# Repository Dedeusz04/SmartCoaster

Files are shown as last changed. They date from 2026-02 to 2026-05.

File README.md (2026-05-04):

# Smart Coaster - ESP8266 Beverage Temperature Monitor

An embedded system built on the **NodeMCU ESP8266** that detects cup presence, monitors beverage temperature in real time, and alerts the user when the drink has cooled to a configured target temperature.

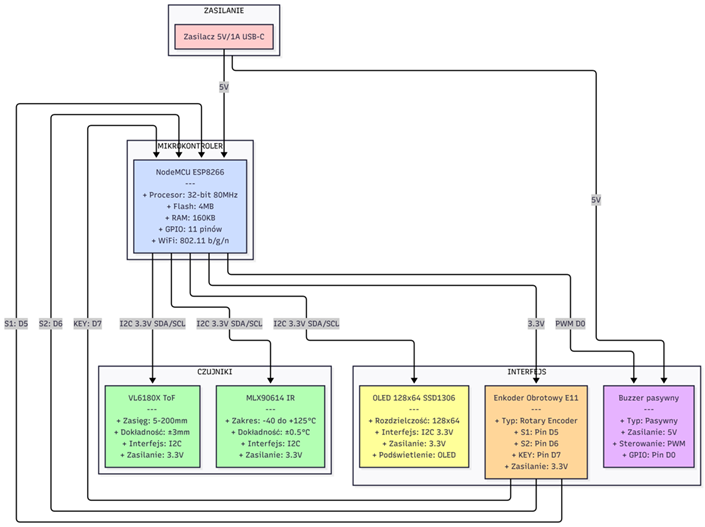
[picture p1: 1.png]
Block Diagram

gif

## Key Features

- Automatic cup detection (VL6180X ToF sensor)
- Non-contact temperature monitoring (MLX90614 IR sensor) with adaptive liquid temperature estimation
- Configurable brew timer and target drinking temperature
- 128×64 OLED display with rotary encoder menu
- Persistent user settings (EEPROM)
- Audible buzzer alerts
- **Mobile Push Notifications** via [ntfy.sh](https://ntfy.sh) (Max priority alarm)
- **Wi-Fi Connectivity** with network state reporting

For a detailed description, refer to the **project report** included in this repository [v1.Raport_Bartosz.Kępa.pdf](v1.Raport_Bartosz.Kępa.pdf).

## Pin Assignment

| Function | NodeMCU Pin | GPIO |
|---|---|---|
| I2C SDA | D2 | GPIO4 |
| I2C SCL | D1 | GPIO5 |
| Encoder S1 | D5 | GPIO14 |
| Encoder S2 | D6 | GPIO12 |
| Encoder Button | D7 | GPIO13 |
| Buzzer | D0 | GPIO16 |

## Build and Flash

Requires [PlatformIO](https://platformio.org/install/ide). All library dependencies are resolved automatically.

```bash
pio run              # compile
pio run -t upload    # flash to board
pio device monitor   # serial monitor (9600 baud)
```

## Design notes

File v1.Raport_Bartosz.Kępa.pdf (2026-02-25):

`

| Katedra Grafiki Wizji Komputerowej i Systemów Cyfrowych | RAu6
Rok akademicki: | Rodzaj studiów*: SSI/NSI/NSM | Przedmiot (Języki Asemblerowe/SMiW): | Grupa | Sekcja
2025/2026 | SSI | SMiW | 2 | 3
Imię: | Bartosz | Prowadzący: OA/JP/KT/GD/GB/KH/AO | JP
Nazwisko: | Kępa

## Raport końcowy SMIW

Temat projektu:
Podkładka pod kubek z funkcją timera i pomiarem temperatury napoju

Data oddania:
dd/mm/rrrr | 26/01/2026

## 1. Wprowadzenie i opis założeń

## 1.1. Cel projektu

Projekt zakłada opracowanie i wykonanie układu mikroprocesorowego pełniącego funkcję podkładki pod kubek. System reaguje na obecność naczynia, odmierza czas parzenia napoju oraz monitoruje temperaturę powierzchni naczynia/cieczy w czasie rzeczywistym.

## 1.2. Główne założenia projektowe

Detekcja obecności kubka
- Pomiar odległości w celu wykrycia obiektu na powierzchni podkładki
- Automatyczne przejście z trybu czuwania do trybu aktywnego po wykryciu kubka
- Zasięg detekcji obiektu: do 20 cm
- Dokładność pomiaru odległości: ±0,5 cm
Pomiar temperatury napoju
- Rejestracja temperatury w zakresie 0°C – 100°C
- Aktualna wartość wyświetlana na ekranie w czasie rzeczywistym
- Komunikat o osiągnięciu temperatury poniżej progu ustawionego przez użytkownika
- Dokładność pomiaru: ±1°C
Timer parzenia
- Odliczanie ustawionego czasu w zakresie 0–10 minut
- Wyświetlanie aktualnego stanu odliczania
- Sygnał dźwiękowy po upływie ustawionego czasu
- Dokładność timera: ±1 sekunda
Interfejs użytkownika
- Możliwość konfiguracji czasu i temperatury
- Czytelny wyświetlacz do prezentacji danych i komunikatów Parametry pracy
- Zakres temperatur otoczenia: 0°C – +40°C
- Zasilanie: 5V DC z zewnętrznego źródła (zasilacz USB-C)

## 2. Opis funkcji urządzenia

## 2.1. Zasada działania

Po wykryciu umieszczenia kubka w obszarze pomiarowym automatycznie uruchamia się odliczanie zaprogramowanego czasu parzenia. Po jego zakończeniu układ generuje sygnał dźwiękowy informujący użytkownika o gotowości napoju. W dalszej fazie urządzenie nadzoruje temperaturę, wyświetlając komunikaty, gdy ciecz osiągnie określony, bezpieczny poziom do spożycia.

## 2.2. Tryby pracy urządzenia

Stan | Opis
WAIT_CUP | Oczekiwanie na postawienie kubka, wyświetlanie komunikatu “Brak kubka”
MENU_TIME | Konfiguracja czasu parzenia (0-10 min) za pomocą enkodera
MENU_TEMP | Konfiguracja temperatury docelowej (0-100°C) za pomocą enkodera
BREWING | Odliczanie czasu parzenia z wyświetlaniem pozostałego czasu i temperatury
DONE | Monitorowanie temperatury do osiągnięcia progu
READY_TO_DRINK | Sygnalizacja gotowości napoju do spożycia

## 2.3. Maszyna stanów

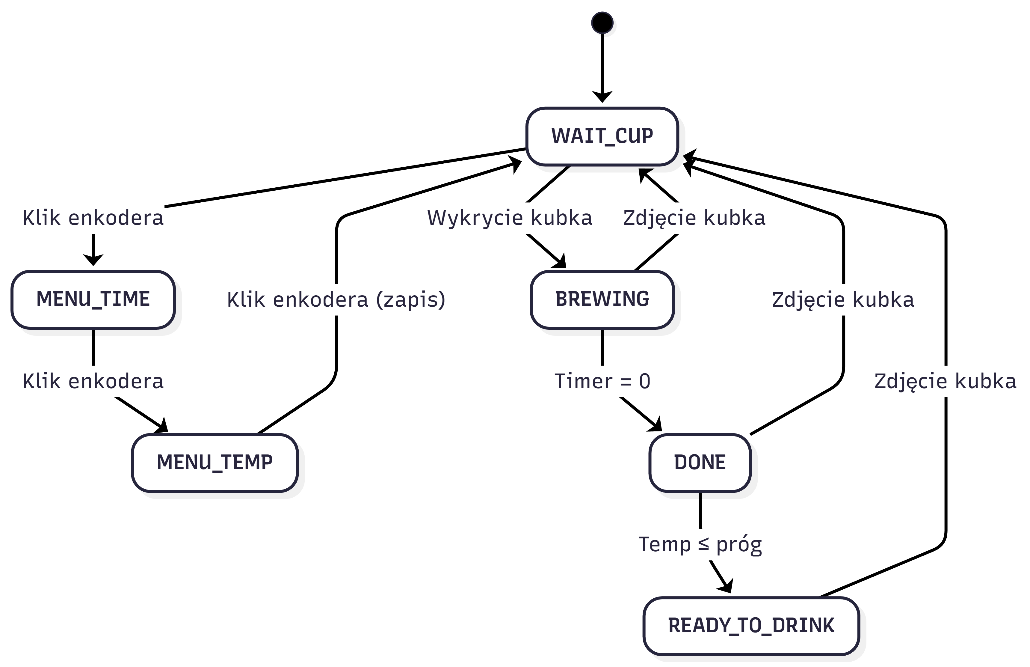
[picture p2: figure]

## 3. Analiza zadania i wybór komponentów

## 3.1. Analiza i wybór czujnika odległości

Wymagania: - Zasięg: do 20 cm
- Dokładność: ±0,5 cm
- Detekcja obecności kubka na podkładce
Porównanie dostępnych rozwiązań:
Parametr | VL6180X | HC-SR04 | GP2Y0A21YK0F | TFMini
Technologia | ToF laser | Ultradźwięki | Podczerwień (Sharp) | Lidar
Zakres pomiarowy | 5-200 mm | 20-4000 mm | 100-800 mm | 30-800 cm
Dokładność | ±3mm | ±3 mm | ±10 mm | ±600mm
Interfejs | I2C | GPIO (Trigger/Echo) | Analogowy | UART/I2C
Napięcie zasilania | 2.8-5V | 5V | 4.5-5.5V | 5V
Pobór prądu | ~20 mA | ~15 mA | ~30 mA | 70mA
Wymiary | 15×8×5 mm | 45×20×15 mm | 30×13×13 mm | 80x70x13m m
Cena orientacyjna | ~10-20 zł | ~5-8 zł | ~15-25 zł | ~50 zł
Zalety | Wysoka dokładność, kompaktowy, I2C | Tani, prosty w obsłudze | Dobra stabilność | Duży zasięg
Wady | Wymaga 3.3V | Duże wymiary, głośny | Niższa dokładność | Zbyt drogi

Wybór: VL6180X
Uzasadnienie: - Najwyższa dokładność pomiaru (±0,3 cm) spełniająca wymaganie ±0,5 cm
- Kompaktowe wymiary idealne do podkładki
- Interfejs I2C pozwala na łatwe połączenie z mikrokontrolerem
- Brak ruchomych części i cichy w działaniu
- Pomimo wyższej ceny, zapewnia profesjonalną jakość pomiaru

## 3.2. Analiza i wybór czujnika temperatury

Wymagania:
- Zakres: 0-100°C
- Dokładność: ±1°C
- Pomiar temperatury powierzchni kubka/napoju
Porównanie dostępnych rozwiązań:
Parametr | MLX90614ESF-BAA | DS18B20 | DHT22 | MAX6675 + termopara K
Typ pomiaru | Bezdotykowy (IR) | Dotykowy (OneWire) | Temperatura + wilgotność | Termopara
Zakres temperatury | -40 do +125°C | -55 do +125°C | -40 do +80°C | 0 do +1024°C
Dokładność | ±0,5°C (0-50°C) | ±0,5°C | ±0,5°C | ±2°C
Interfejs | I2C (SMBus) | 1-Wire | Własny protokół | SPI
Napięcie zasilania | 3.0-5V | 3.0-5.5V | 3.3-5.5V | 3.3-5V
Czas odpowiedzi | <1s | ~750ms (12-bit) | ~2s | ~0.5s
Cena orientacyjna | ~15-40 zł | ~8-12 zł | ~15-20 zł | ~25-35 zł
Zalety | Pomiar bezkontaktowy, szybki, precyzyjny | Tani, dokładny | Dodatkowa funkcja wilgotności | Wysokie temp.
Wady | Droższy | Wymaga kontaktu z cieczą | Wolny, mierzy powietrze | Wymaga kalibr.

Wybór: MLX90614ESF-BAA
Uzasadnienie: - Pomiar bezdotykowy idealny dla podkładki (czujnik pod kubkiem mierzy temperaturę dna)
- Wysoka dokładność ±0,5°C (lepiej niż wymagane ±1°C)
- Szybki czas odpowiedzi dla monitoringu w czasie rzeczywistym
- Interfejs I2C kompatybilny z VL6180X (można użyć tej samej magistrali)
- Profesjonalne rozwiązanie, bezpieczne (brak kontaktu z gorącym kubkiem)

## 3.3. Analiza i wybór wyświetlacza

Wymagania:
- Wyświetlanie temperatury, czasu, komunikatów
- Czytelność
- Możliwość podłączenia do mikrokontrolera
Porównanie dostępnych rozwiązań:
Parametr | LCD I2C 16×2 | OLED SSD1306 128×64 | LCD 16×2 (parallel) | TFT 1.8” ST7735
Rozdzielczość | 16 znaków × 2 linie | 128×64 pikseli | 16 znaków × 2 linie | 128×160 pikseli
Interfejs | I2C (2 piny) | I2C / SPI | Równoległy (6-8 pinów) | SPI (5 pinów)
Napięcie zasilania | 5V | 3.3-5V | 5V | 3.3-5V
Pobór prądu | ~20 mA | ~20 mA | ~20 mA | ~40mA
Kontrast/czytel ność | Bardzo dobry | Doskonały, wysoki kontrast | Bardzo dobry | Dobry
Wymiary | 80×36×18 mm | 27×27×4 mm | 80×36×12 mm | 35×50×5 mm
Cena orientacyjna | ~12-18 zł | ~6-25 zł | ~10-15 zł | ~20-30 zł
Zalety | Prosty I2C, duże znaki | Kompaktowy, graficzny, elegancki | Najtańszy | Kolorowy
Wady | Większe wymiary | Wymaga biblioteki graficznej | Zajmuje dużo GPIO | Wymaga więcej RAM

Wybór: OLED SSD1306 (zmiana względem analizy)
Uzasadnienie: - Kompaktowe wymiary (27×27×4 mm)
- Wysoki kontrast i czytelność
- Możliwość wyświetlania grafiki i większych czcionek
- Energooszczędny, komunikacja i2c, działanie na 3,3V

## 3.4. Analiza i wybór przycisków sterujących

Wymagania:
- Konfiguracja czasu i temperatury
- Minimum 3 przyciski (menu, góra, dół)
Porównanie dostępnych rozwiązań:
Parametr | Tact Switch 6×6mm | Przyciski membranowe | Przyciski kapturowe | EC11 Rotary Encoder
Typ | Mikroswitch taktylny | Membrana z kontaktem | Przycisk z osłoną | Encoder z przyciskiem
Trwałość | 100 000 cykli | 1 000 000 cykli | 50 000 cykli | 30 000 obrotów
Siła nacisku | ~160 gF | ~200-300 gF | ~250 gF | Obrót: ~100 gF
Wymiary | 6×6×5 mm | 12×12 mm | 12×12 mm | 12.5×12.5 mm
Cena (3 szt.) | ~1-2 zł | ~8-15 zł | ~3-6 zł | ~3-5 zł (1 szt.)
Zalety | Tanie, kompaktowe | Profesjonalny wygląd | Estetyczne | Intuicyjna obsługa, 3 funkcje w 1
Wady | Wymaga nakładek | Droższe | Większe wymiary | Droższy, większy

Wybór: EC11 Rotary Encoder z przyciskiem
Uzasadnienie: - Intuicyjna obsługa
– obracanie jest bardziej naturalne niż wielokrotne klikanie
- Szybka nawigacja zmiana wartości (czas 0-10 min, temperatura 0-100°C) jest znacznie szybsza
- 3 funkcje w 1 elemencie: obrót lewo/prawo + wciśnięcie
- Oszczędność miejsca – zamiast 3 przycisków tylko 1 komponent
- Taktylny feedback – kliknięcia przy obrocie (20 impulsów/obrót)

## 3.5. Analiza i wybór buzzera

Wymagania:
- Sygnalizacja dźwiękowa po zakończeniu timera
- Wyraźny dźwięk
Porównanie dostępnych rozwiązań:
Parametr | Buzzer pasywny | Buzzer aktywny | Głośniczek piezo
Typ | Wymaga sygnału PWM | Wbudowany generator | Piezoelektryczny
Napięcie | 3-12V | 3-12V | 3-24V
Głośność | 80-90 dB (regulowana) | 85 dB (stała) | 70-100 dB
Możliwości | Różne melodie/tony | Jeden stały ton | Różne częstotliwości
Sterowanie | PWM (1 pin) | ON/OFF (1 pin) | PWM (1 pin)
Cena orientacyjna | ~1-4 zł | ~2-3 zł | ~3-6 zł
Zalety | Możliwość melodii | Najprostszy w obsłudze | Najgłośniejszy
Wady | Wymaga programowania PWM | Brak zmiany tonu | Droższy

Wybór: Buzzer pasywny
Uzasadnienie: - Możliwość zaprogramowania różnych melodii/tonów dla różnych zdarzeń -Regulacja głośności przez zmianę wypełnienia PWM - Większa elastyczność funkcjonalna -ESP8266 bez problemu generuje sygnał PWM

## 3.6. Analiza i wybór mikrokontrolera

Podsumowanie wymagań interfejsów:
- I2C: 3 urządzenia (OLED, VL6180X, MLX90614)
– 2 piny (SDA, SCL) - GPIO cyfrowe: EC11 Rotary Encoder – 3 piny - PWM: 1 buzzer
– 1 pin - Łącznie: minimum 4 pinów GPIO + I2C
Porównanie dostępnych rozwiązań:
Parametr | NodeMCU ESP8266 | Arduino Nano | STM32F103 | Arduino Uno
Procesor | Tensilica L106 32-bit | ATmega328P 8-bit | ARM Cortex-M3 | ATmega328P
Częstotliwo ść | 80/160 MHz | 16 MHz | 72 MHz | 16 MHz
Flash | 4 MB | 32 KB | 64/128 KB | 32 KB
RAM | 160 KB | 2 KB | 20 KB | 2 KB
GPIO | 11 pinów | 14 pinów | 37 pinów | 14 pinów
Interfejsy | I2C, SPI, UART, PWM | I2C, SPI, UART, PWM | 2×I2C, 2×SPI, PWM | I2C, SPI, UART
Napięcie logiki | 3.3V | 5V | 3.3V | 5V
Wbudowane WiFi | Tak | Nie | Nie | Nie
Pobór prądu | ~80 mA | ~20 mA | ~40 mA | ~53 mA
Cena orientacyjna | ~15-25 zł | ~20-30 zł | ~10-15 zł | ~25-35 zł

Wybór: NodeMCU ESP8266
Uzasadnienie:
- Wystarczająca liczba GPIO: 11 pinów (potrzeba 4 + I2C)
- Wbudowany moduł WiFi: możliwość przyszłej rozbudowy (zdalna kontrola, notyfikacje)
- Szybki procesor: 80 MHz zapewnia płynne działanie timera i odświeżania wyświetlacza
- Duża pamięć: 4 MB Flash, 160 KB RAM- komfortowe programowanie
- I2C hardware: wbudowana obsługa magistrali I2C

-PWM: możliwość generowania sygnału dla buzzera
- Społeczność: ogromne wsparcie, biblioteki, przykłady

## 3.7. Analiza zasilania

Wymagania prądowe (maksymalne):

Urządzenie | Napięcie | Prąd
NodeMCU ESP8266 3.3V (z 5V) 200 mA
OLED SSD 1306 | 3.3V | 20 mA
VL53L0X | 3.3V | 20 mA
MLX90614 | 3.3V | 5 mA
Przyciski | - | <1 mA
Buzzer pasywny | 5V | 30 mA
SUMA | 5V | ~275 mA

Porównanie źródeł zasilania:

Źródło | Napięcie wyjściowe | Prąd max | Zastosowanie | Cena
Zasilacz sieciowy 5V/1A | 5V DC | 1000 mA | Stacjonarne urządzenia | ~10-15 zł
Powerbank USB 5V | 5V DC | 1000-2000 mA | Mobilne | ~30-50 zł
Baterie 4×AA z przetwórnicą | 5V DC (z 6V) | 500 mA | Przenośne | ~20 zł (baterie + przetwornica)

Wybór: Zasilacz sieciowy 5V/1A (wtyk USB-C)

Uzasadnienie:

- Pobór prądu ~275 mA << 1000 mA (duży zapas bezpieczeństwa)
- Urządzenie stacjonarne (podkładka pod kubek) – nie wymaga mobilności
- Najbardziej ekonomiczne i stabilne rozwiązanie
- NodeMCU posiada port USB-C do zasilania
- Brak konieczności wymiany baterii

## 3.8 Analiza różnych sposobów rozwiązania zadania

Koncepcja A: Układ z czujnikami bezkontaktowymi (WYBRANA) Opis: Czujnik laserowy ToF (VL6180X) + czujnik IR (MLX90614) + ESP8266 Zalety:
- Brak kontaktu fizycznego z kubkiem (higieniczne)
- Wysoka dokładność obu pomiarów
- Możliwość rozbudowy o WiFi/IoT
- Kompaktowa konstrukcja
Wady:
- Wyższy koszt (~140 zł)
- Czujnik IR wymaga kalibracji dla różnych materiałów

Koncepcja B: Układ z czujnikami dotykowymi
Opis: Czujnik ultradźwiękowy (HC-SR04) + sonda dotykowa (DS18B20) Zalety:
- Niższy koszt (~80 zł, oszczędność 60 zł)
- Bardzo dokładny pomiar temperatury przy kontakcie
- Prostsza kalibracja
Wady:
- Wymaga precyzyjnego ustawienia kubka
- Sonda może się brudzić
- Większe wymiary czujnika ultradźwiękowego
- Mniej profesjonalny wygląd

Koncepcja C: Układ z wagą elektroniczną
Opis: Czujnik wagi (HX711 + load cell) + termopara K Zalety:
- Niezawodna detekcja kubka (pomiar masy)
- Możliwość dodatkowych funkcji (pomiar ilości płynu)
- Termopara działa do 1000°C
Wady:
- Skomplikowana konstrukcja mechaniczna
- Najwyższy koszt (~180 zł)
- Większe wymiary
- Trudniejsza kalibracja

Wybór: Koncepcja A - optymalne połączenie dokładności, higieny i możliwości rozbudowy przy akceptowalnym koszcie.

## 4. Zmiany wprowadzone po analizie

## 4.1. Zmiana wyświetlacza

Aspekt | Analiza (LCD I2C 16×2) | Realizacja (OLED SSD1306)
Rozdzielczość | 16×2 znaki | 128×64 pikseli
Kontrast | Podświetlenie LED | Samoemisyjny, wysoki kontrast
Wymiary | 80×36×18 mm | 27×27×4 mm
Biblioteka | LiquidCrystal_I2C | ss_oled

Uzasadnienie: OLED oferuje większą elastyczność w wyświetlaniu informacji, mniejsze wymiary i lepszy wygląd urządzenia.

## 4.2. Sterowanie buzzerem

Aspekt | Analiza | Realizacja
Zasilanie | 3.3V bezpośrednio | 5V przez tranzystor
Sterowanie | GPIO bezpośrednio | PWM → 2N2222 → Buzzer
Zabezpieczenie | Brak | Dioda DO-213AA(SOD-80)

Uzasadnienie: Buzzer 5V zapewnia głośniejszy dźwięk. Tranzystor 2N2222 odciąża GPIO ESP8266, a dioda zabezpieczająca chroni tranzystor przed przepięciami indukcyjnymi.

## 4.3. Konstrukcja dwupłytkowa

Płytka | Komponenty
Główna (Main PCB) | ESP8266, OLED, Rotary Encoder, Buzzer, złącze J1
Czujników (Sensor PCB) | VL6180X, MLX90614, złącze J1

Połączenie: Kable DuPont przez złącze 2×5 pin (5-534237-8)
Uzasadnienie: Rozdzielenie pozwala na umieszczenie czujników w optymalnej pozycji względem kubka, niezależnie od elektroniki głównej.

## 5. Specyfikacja wewnętrzna urządzenia

## 5.1. Schemat blokowy

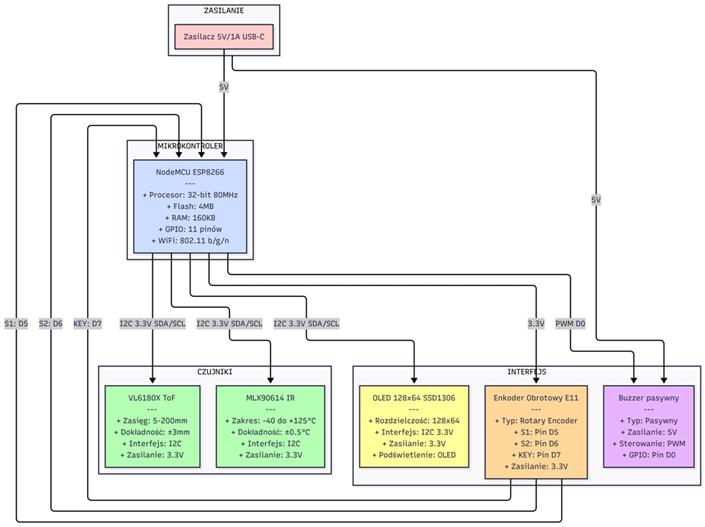
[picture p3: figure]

Schemat blokowy systemu
Opis połączeń:
- Zasilanie: 5V/1A USB-C → NodeMCU ESP8266 (wbudowany regulator 3.3V)
- Magistrala I2C: SDA (D2), SCL (D1) → OLED, MLX90614, VL6180X
- Enkoder: S1 (D5), S2 (D6), KEY (D7)
- Buzzer: PWM (D0) → Tranzystor → Buzzer 5V

## 5.2. Schemat ideowy

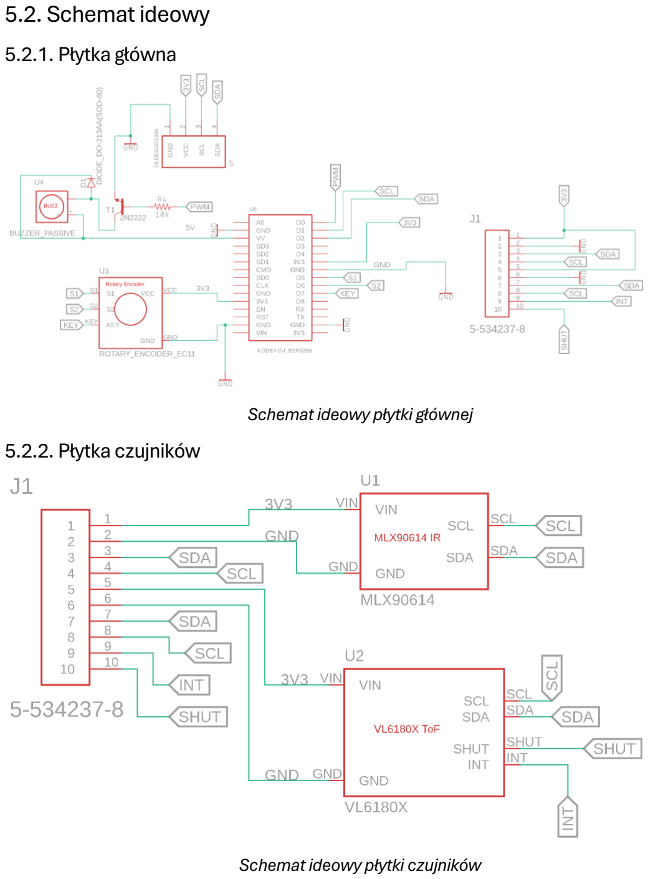
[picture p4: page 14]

5.2.1. Płytka główna

Schemat ideowy płytki głównej
5.2.2. Płytka czujników

Schemat ideowy płytki czujników

## 5.3. Opis bloków funkcjonalnych

5.3.1. Blok zasilania

Układ zasilany jest z zewnętrznego zasilacza 5V/1A przez port USB-C modułu NodeMCU. Wbudowany regulator napięcia AMS1117-3.3 dostarcza napięcie 3.3V dla:
- Czujnika VL6180X
-Czujnika MLX90614
- Wyświetlacza OLED
- Enkodera obrotowego
Buzzer zasilany jest bezpośrednio z 5V.
5.3.2. Blok pomiaru odległości (VL6180X)

Czujnik ToF mierzy odległość do obiektu (kubka) w zakresie 5-200 mm. Komunikacja I2C na adresie 0x29. Pomiar wykonywany co 400 ms w celu oszczędzania energii i ochrony termicznej.

Funkcja measureDistance():

1. float measureDistance() {
2. uint8_t range = vl.readRange();
3. return (vl.readRangeStatus() == VL6180X_ERROR_NONE) ? range : -1;
4. }
5.3.3. Blok pomiaru temperatury (MLX90614)

Czujnik IR mierzy temperaturę obiektu bezdotykowo. Komunikacja I2C na adresie 0x5A. Pomiar temperatury z funkcją estymacji temperatury cieczy.
Algorytm estymacji temperatury kompensuje różnicę między temperaturą dna kubka a rzeczywistą temperaturą cieczy:
1. float estimateLiquidTemp(float rawBottomTemp, float ambientTemp) {
2. float diff = rawBottomTemp - ambientTemp;
3. float adaptiveCoeff = baseFactor * coefficientTable[diff];
4. return rawBottomTemp + (diff * adaptiveCoeff);
5. }
5.3.4. Blok interfejsu użytkownika

Wyświetlacz OLED SSD1306:
- Adres I2C: 0x3C
- Biblioteka: ss_oled

- Tryby wyświetlania: FONT_NORMAL, FONT_STRETCHED Enkoder EC11: - Obsługa przerwań na pinach S1 i S2 (CHANGE)
- Dekodowanie quadrature dla dokładnej detekcji kierunku
- Przycisk z debounce 250 ms
5.3.5. Blok sygnalizacji dźwiękowej

Buzzer pasywny sterowany PWM przez tranzystor 2N2222:
- Rezystor bazowy: 10kΩ
- Dioda zabezpieczająca: DO-213AA
- Funkcja beep(frequency, duration) generuje sygnał PWM

## 5.4. Schemat montażowy i projekt PCB

5.4.1. Płytka główna - warstwa TOP (czerwona)

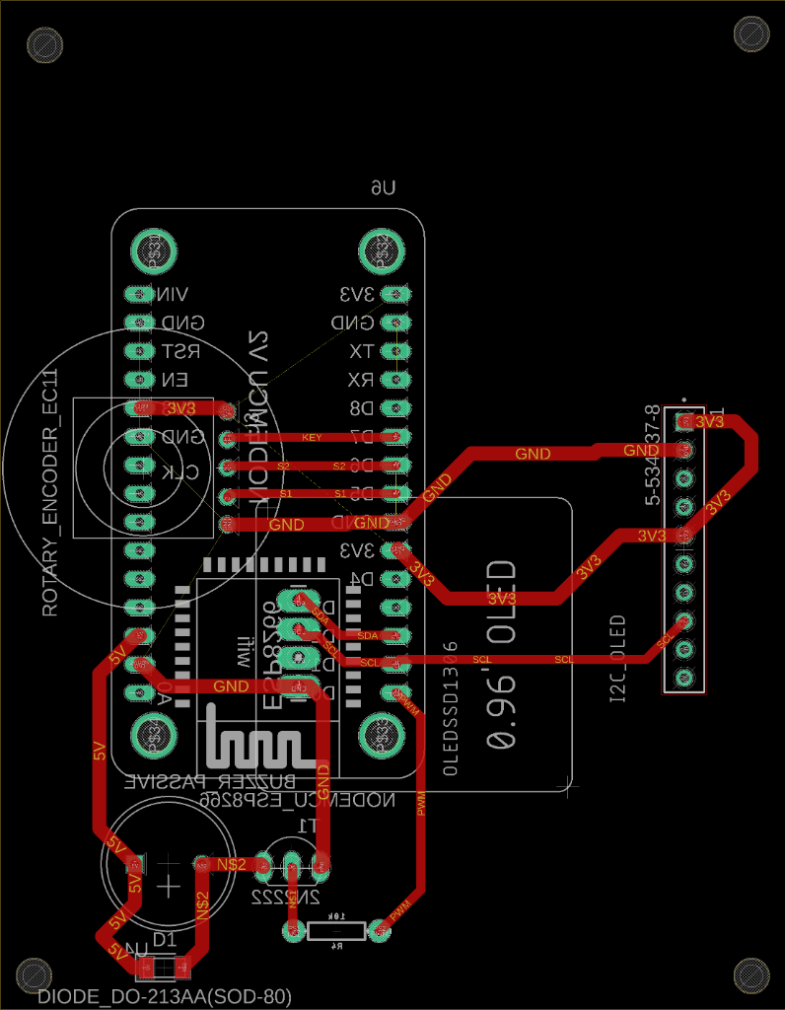
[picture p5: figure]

PCB płytki głównej - warstwa TOP

5.4.2. Płytka główna - warstwa BOTTOM (niebieska)

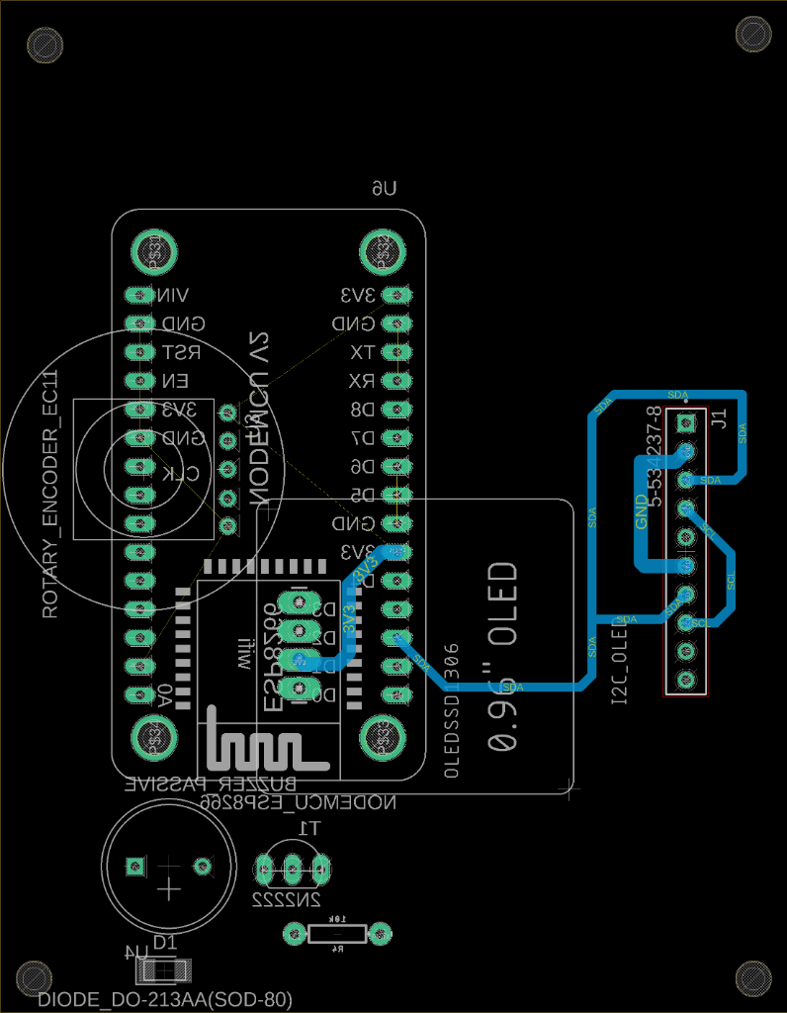
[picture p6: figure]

PCB płytki głównej - warstwa BOTTOM

5.4.3. Płytka czujników - warstwa TOP (czerwona)

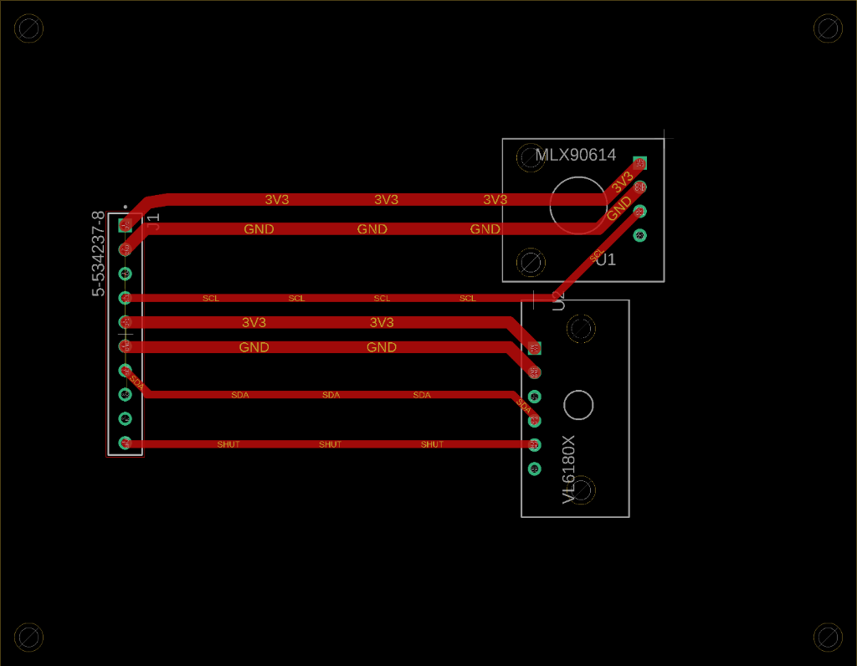
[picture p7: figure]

PCB płytki czujników - warstwa TOP

5.4.4. Płytka czujników - warstwa BOTTOM (niebieska)

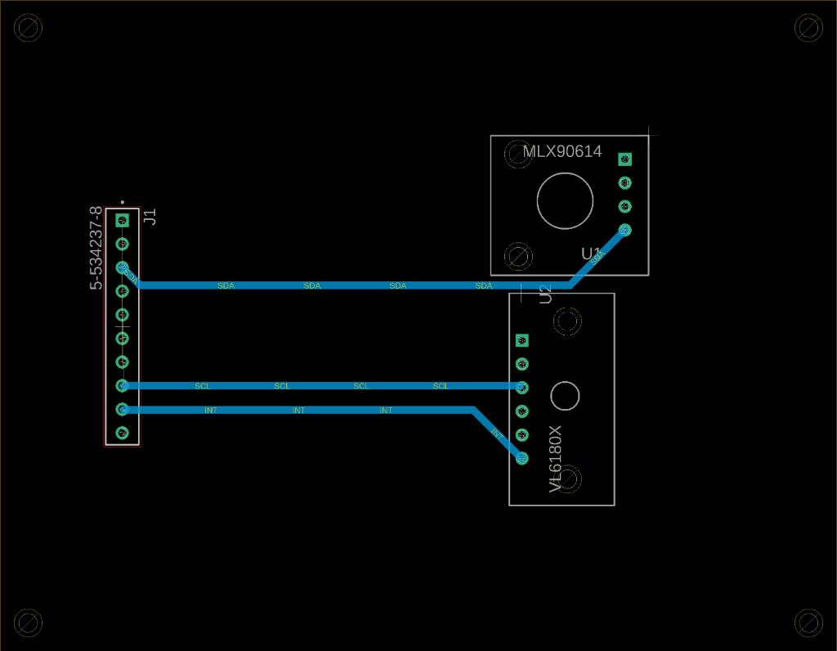
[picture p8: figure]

PCB płytki czujników - warstwa BOTTOM

## 5.5. Lista elementów

Płytka główna
Oznaczenie | Element | Wartość/Typ | Ilość | Cena
U6 | Mikrokontroler | NodeMCU ESP8266 | 1 | 15 zł
U7 | Wyświetlacz | OLED SSD1306 128×64 0.96” | 1 | 6 zł
U3 | Enkoder | EC11 z przyciskiem | 1 | 3.50 zł
U4 | Buzzer | Pasywny 5V | 1 | 1 zł
T1 | Tranzystor | 2N2222 | 1 | 0.5 zł
D1 | Dioda | DO-213AA(SOD-80) | 1 | 0.5 zł
R4 | Rezystor | 10kΩ | 1 | 0.1 zł
J1 | Złącze | 5-534237-8 (5 pin) | 2 | 1 zł
- | Złącza do modułów | 5-534237-8 (4,5,15,2 pin) | 5 | 1.5 zł
- | PCB | Płytka uniwersalna | 2 | 4 zł

Płytka czujników
Oznaczenie | Element | Wartość/Typ | Ilość | Cena
U1 | Czujnik temperatury | MLX90614ESF-BAA | 1 | 15 zł
U2 | Czujnik odległości | VL6180X ToF | 1 | 10 zł
J1 | Złącze | 5-534237-8 (5 pin) | 2 | 1 zł
- | Złącza do modułów | 5-534237-8 (4pin) | 2 | 1 zł
Inne
Element | Opis | Ilość | Cena
Kable DuPont | Male-male | 8 | 1 zł
Zasilacz | 5V/1A USB-C | 1 | 10 zł
Przewody | Różne do montażu | - | ~1 zł
Obudowa | Pudełko plastikowe | 1 | 7 zł

Suma: ~79.1 zł

## 5.6. Opis montażu

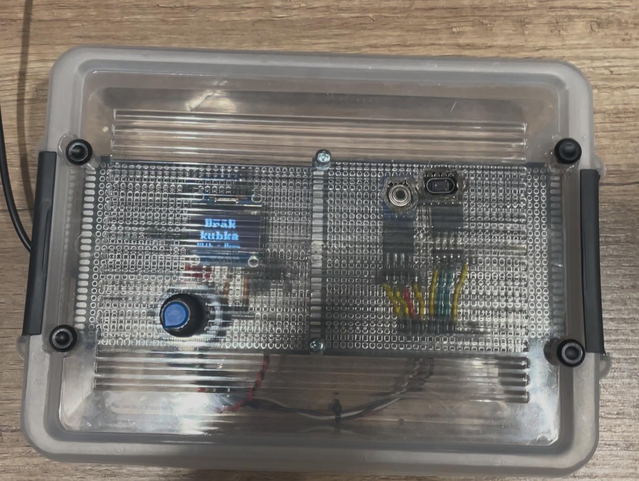
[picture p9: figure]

Widok urządzenia w obudowie

Urządzenie zostało umieszczone w obudowie z tworzywa sztucznego z przezroczystą pokrywą. Układ elektroniczny, zmontowany na płytce uniwersalnej, został trwale przymocowany do wewnętrznej strony pokrywy za pomocą śrub montażowych.
W pokrywie wykonano otwory dla kluczowych elementów interfejsu i sensorów.
Takie rozwiązanie konstrukcyjne zapewnia ochronę mechaniczną układu przy jednoczesnym zachowaniu funkcjonalności sensorów i czytelności wyświetlacza OLED Urządzenie składa się z dwóch płytek PCB połączonych kablem DuPont male-male przez złącza 2×5pin (5-534237-8). Wszystkie moduły posiadają goldpiny male, a do płytki podłączane są przez connectory (goldpiny) female, co umożliwia łatwą wymianę komponentów.
Płytka główna - podłączenie modułów:
Moduł | Złacza na PCB | Piny
NodeMCU ESP8266 | Connector 2×15 fem. | Wszystkie piny modułu
OLED SSD1306 | Connector 1×4 fem. | GND, VCC, SCL, SDA
Enkoder EC11 | Connector 1×5 fem. | S1, S2, KEY, VCC, GND
Buzzer pasywny | Connector 1×2 fem. | +, - (przez tranzystor)
Złącze J1 | Connector 2×5 fem. | Do płytki czujników
Płytka czujników - podłączenie modułów:
Moduł | Złącza na PCB | Piny
MLX90614 | Connector 1×4 fem. | VIN, GND, SCL, SDA
VL6180X | Connector 1×4 fem. | VIN, GND, SCL, SDA, (SHUT, INT)-nieużywane
Złącze J1 | Connector 2×5 fem. | Do płytki głównej

Połączenie płytek kablem DuPont (9-10 pusty):
Pin | Płytka główna | Płytka czujników
1 | 3V3 | VIN (MLX90614)
2 | GND | GND (MLX90614)
3 | SDA (D2) | SDA (MLX90614)
4 | SCL (D1) | SCL (MLX90614)
5 | 3V3 | VIN (VL6180X)
6 | GND | GND (VL6180X)
7 | SDA (D2) | SDA (VL6180X)
8 | SCL (D1) | SCL (VL6180X)

## 5.7. Programowanie układu

5.7.1. Środowisko programistyczne
- IDE: PlatformIO (w Visual Studio Code)
- Framework: Arduino
- Platforma: espressif8266
- Board: nodemcuv2
5.7.2. Konfiguracja projektu (platformio.ini)
1. [env:nodemcuv2]
2. platform = espressif8266
3. board = nodemcuv2
4. framework = arduino
5. monitor_speed = 115200
6.
7. lib_deps =
8. Wire
9. SPI
10. Adafruit BusIO
11. Adafruit Unified Sensor
12. https://github.com/adafruit/Adafruit-MLX90614-Library.git
13. https://github.com/adafruit/Adafruit_VL6180X.git
14. https://github.com/bitbank2/ss_oled.git
15.
16. build_flags =
17. -D PIO_FRAMEWORK_ARDUINO_ESPRESSIF_SDK22x_191122 18.
19. board_build.ldscript = eagle.flash.4m1m.ld
5.7.3. Procedura programowania
1. Podłączyć NodeMCU do komputera przez USB
2. Wybrać odpowiedni port COM w PlatformIO
3. Skompilować projekt: pio run
4. Wgrać firmware: pio run --target upload
5. Otworzyć monitor szeregowy: pio device monitor

## 5.8. Uruchamianie i testowanie

5.8.1. Procedura uruchomienia
1. Podłączyć zasilacz 5V/1A
2. Obserwować sekwencję startową na wyświetlaczu:
- “Coaster” - logo startu
- “Sensors: MLX: OK, VL: OK” - status czujników
3. Po ~2 sekundach wyświetla się “Brak kubka”
5.8.2. Testy funkcjonalne
Test | Procedura | Oczekiwany rezultat
Detekcja kubka | Umieścić kubek nad czujnikiem | Wyświetla “Kubek wykryty”, rozpoczyna parzenie
Timer | Ustawić czas, postawić kubek | Odliczanie widoczne na ekranie
Pomiar temperatury | Postawić gorący kubek | Wyświetla temperaturę estymowaną
Enkoder | Obracać pokrętło w menu | Zmiana wartości czasu/temperatury
Buzzer | Zakończyć timer | Dźwięk sygnalizacyjny
Zapis EEPROM | Zmienić ustawienia, wyłączyć/włączyć | Ustawienia zachowane
5.8.3. Weryfikacja czujników

Monitor szeregowy wyświetla co 5 sekund:
Raw: XX.XC, Est: XX.XC, Peak: XX.XC

## 5.9. Algorytm oprogramowania

5.9.1. Schemat blokowy programu

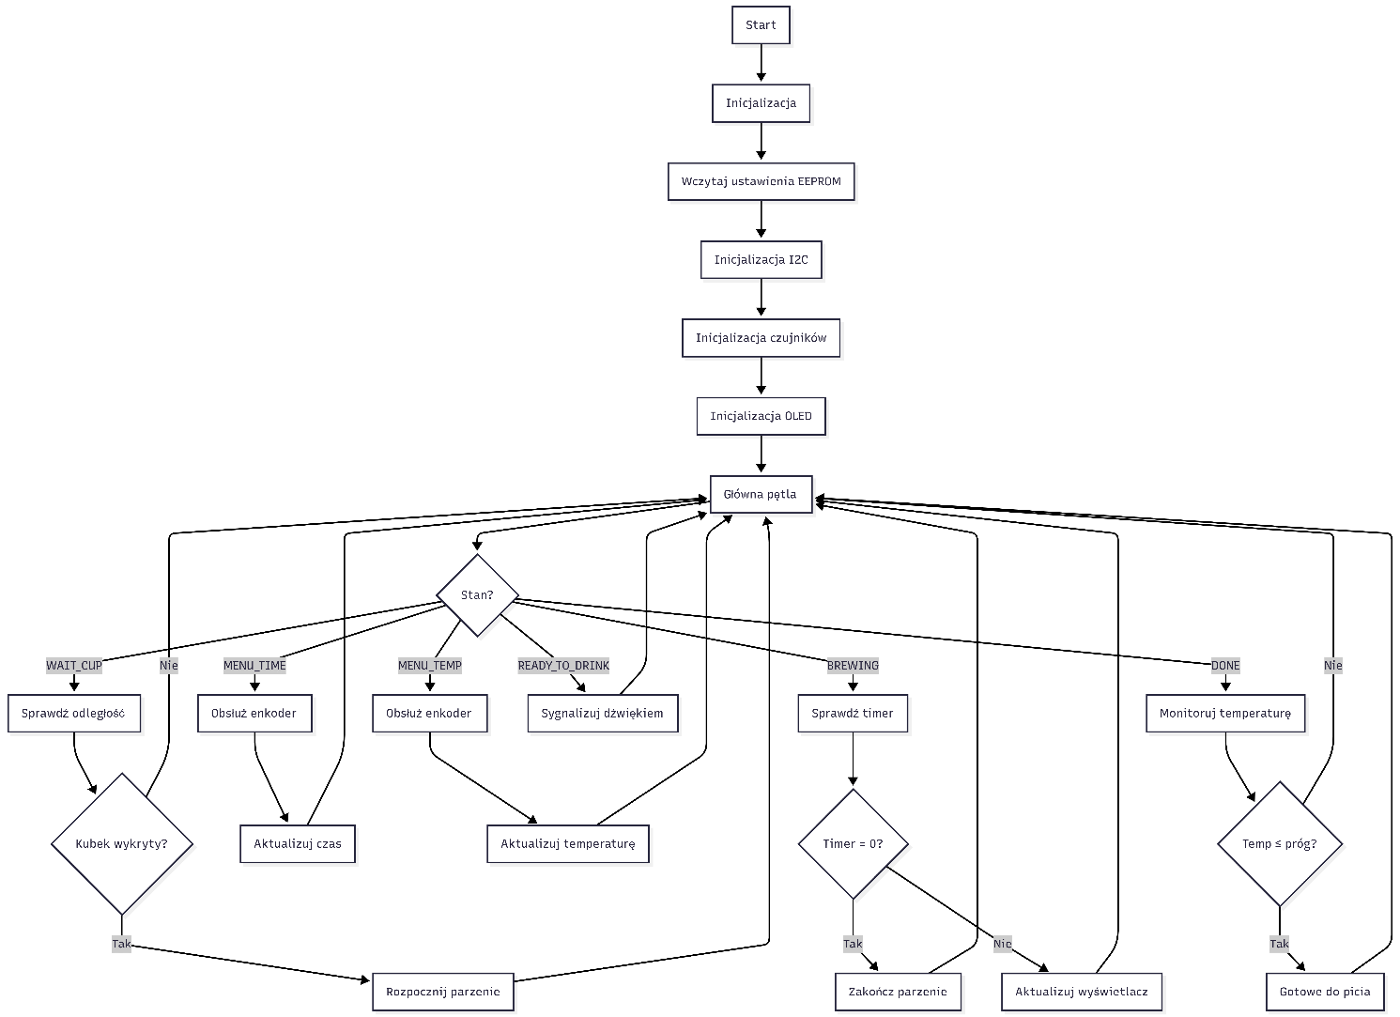
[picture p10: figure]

## 5.10. Opis zmiennych

Zmienne globalne - ustawienia
Zmienna | Typ | Zakres | Opis
timeSet | unsigned long | 0-600 | Ustawiony czas parzenia [s]
tempThreshold | float | 0-100 | Temperatura docelowa [°C]
brewDuration | unsigned long | 0-600 | Aktualny czas parzenia [s]
brewStartTime | unsigned long | - | Znacznik czasu rozpoczęcia parzenia [ms]

Zmienne globalne - stan
Zmienna | Typ | Opis
state | enum State | Aktualny stan maszyny stanów
cupDetected | bool | Flaga wykrycia kubka
currentTemp | float | Aktualna estymowana temperatura cieczy [°C]
rawBottomTemp | float | Surowa temperatura dna kubka [°C]
peakTemp | float | Szczytowa temperatura zarejestrowana [°C]
fixedAmbient | float | Snapshot temperatury otoczenia przy postawieniu kubka [°C]

Zmienne globalne - enkoder
Zmienna | Typ | Opis
encoderPosition | volatile int | Pozycja enkodera (aktualizowana przez przerwania)
lastEncoded | volatile int | Poprzedni stan pinów enkodera
lastButtonTime | unsigned long | Znacznik czasu ostatniego naciśnięcia przycisku

Zmienne globalne - wyświetlacz
Zmienna | Typ | Opis
needDisplayUpdate | bool | Flaga konieczności odświeżenia wyświetlacza
lastDrawnState | State | Ostatni narysowany stan (optymalizacja rysowania)
lastDisplayDrawTime | unsigned long | Znacznik czasu ostatniego odświeżenia

Stałe konfiguracyjne
Stała | Wartość | Opis
MAX_DISTANCE | 200 | Maksymalna odległość

Stała | Wartość | Opis
| | detekcji kubka [mm]
MIN_TIME / MAX_TIME | 0 / 600 | Zakres czasu parzenia [s]
MIN_TEMP / MAX_TEMP | 0 / 100 | Zakres temperatury docelowej [°C]
DEFAULT_TIME | 180 | Domyślny czas parzenia (3 min)
DEFAULT_TEMP | 55 | Domyślna temperatura docelowa [°C]
SAFETY_TEMP_THRESHOLD | 45.0 | Próg ochrony termicznej czujnika [°C]

## 5.11. Opis procedur

5.11.1. Procedura setup()

Cel: Inicjalizacja systemu
Działanie: 1. Inicjalizacja UART (115200 baud) dla debugowania
2. Wczytanie ustawień z EEPROM
3. Konfiguracja pinów GPIO (enkoder, buzzer)
4. Podłączenie przerwań do pinów enkodera
5. Inicjalizacja magistrali I2C (100 kHz)
6. Inicjalizacja wyświetlacza OLED
7. Inicjalizacja czujników MLX90614 i VL6180X
8. Wyświetlenie statusu inicjalizacji
9. Snapshot temperatury otoczenia
5.11.2. Procedura loop()

Cel: Główna pętla programu
Działanie: 1. Obsługa enkodera (odczyt pozycji, przycisk)
2. Sprawdzanie odległości (detekcja kubka) co 400 ms

3. Obsługa alarmu gotowości (beep co 2 s)
4. Odczyt temperatury co 1 s (gdy kubek wykryty)
5. Logika wykrywania gotowości do picia
6. Reset stanu przy zdjęciu kubka
7. Obsługa timera parzenia
8. Aktualizacja wyświetlacza
5.11.3. Procedura handleEncoderInterrupt() (ISR)

Cel: Obsługa przerwania enkodera z dekodowaniem quadrature Typ: IRAM_ATTR (funkcja przerwania)
Działanie:
1. void IRAM_ATTR handleEncoderInterrupt() {
2. int MSB = digitalRead(ENC_S1);
3. int LSB = digitalRead(ENC_S2);
4. int encoded = (MSB << 1) | LSB;
5. int sum = (lastEncoded << 2) | encoded;
6.
7. // Tablica stanów
8. if(sum == 0b1101 || sum == 0b0100 || sum == 0b0010 || sum == 0b1011) {
9. encoderPosition++;
10. }
11. if(sum == 0b1110 || sum == 0b0111 || sum == 0b0001 || sum == 0b1000) {
12. encoderPosition--;
13. }
14. lastEncoded = encoded;
15. }
Opis: Funkcja dekoduje sygnały A i B enkodera metodą quadrature, co pozwala na dokładne wykrycie kierunku obrotu. Przerwanie wywoływane jest przy każdej zmianie stanu (CHANGE) na obu pinach.
5.11.4. Procedura estimateLiquidTemp()

Cel: Estymacja temperatury cieczy na podstawie temperatury dna kubka
Parametry: - rawBottomTemp - temperatura dna kubka [°C] - ambientTemp - temperatura otoczenia [°C]
Zwraca: Estymowana temperatura cieczy [°C]

Algorytm: 1. Oblicz różnicę: diff = rawBottomTemp - ambientTemp
2. Wybierz współczynnik adaptacyjny na podstawie zakresu różnicy
3. Oblicz estymację: liquidTemp = rawBottomTemp + (diff * adaptiveCoeff)
5.11.5. Procedura encoderClick()

Cel: Obsługa kliknięcia przycisku enkodera
Maszyna stanów: - WAIT_CUP → MENU_TIME
- MENU_TIME → MENU_TEMP
- MENU_TEMP → WAIT_CUP (z zapisem ustawień) Działanie:
1. void encoderClick() {
2. State oldState = state;
3. if (state == WAIT_CUP) state = MENU_TIME;
4. else if (state == MENU_TIME) state = MENU_TEMP;
5. else if (state == MENU_TEMP) {
6. state = WAIT_CUP;
7. saveSettings();
8. beep(2500, 20);
9. }
10. if (oldState != state) {
11. beep(2000, 20);
12. needDisplayUpdate = true;
13. }
14. }
5.11.6. Procedura drawScreenContent()

Cel: Rysowanie zawartości ekranu w zależności od stanu Tryby wyświetlania:

Stan | Zawartość ekranu
WAIT_CUP (brak kubka) | “Brak kubka” + “Klik = Menu”
WAIT_CUP (kubek) | “Kubek wykryty”
MENU_TIME | “Czas parzenia: MM:SS”
MENU_TEMP | “Ustaw Temp: XX C”
BREWING | “Parzenie” + “MM:SS” + “Liq: XX C”
DONE | “Stygnie/Grzanie” + “Cel: XX C” + “Akt: XX C”
READY_TO_DRINK | “GOTOWE!” + “XX C”

5.11.7. Procedury pomocnicze
Procedura | Opis
loadSettings() | Wczytuje czas i temperaturę z EEPROM
saveSettings() | Zapisuje czas i temperaturę do EEPROM
measureDistance() | Odczytuje odległość z VL6180X
startBrewing() | Inicjalizuje stan BREWING
finishBrewing() | Kończy parzenie, przechodzi do DONE
remaining() | Oblicza pozostały czas parzenia
beep(freq, dur) | Generuje dźwięk buzzera
formatTime(sec, buf) | Formatuje sekundy do MM:SS
triggerReady() | Przechodzi do stanu READY_TO_DRINK

## 6. Specyfikacja zewnętrzna urządzenia

## 6.1. Elementy sterujące

Enkoder obrotowy EC11
Akcja | Funkcja
Obrót w prawo | Zwiększenie wartości (czas +10s, temp +1°C)
Obrót w lewo | Zmniejszenie wartości (czas -10s, temp -1°C)
Kliknięcie | Przełączanie menu / zatwierdzenie
Sekwencja menu
WAIT_CUP → [KLIK] → MENU_TIME → [KLIK] → MENU_TEMP → [KLIK] → WAIT_CUP (zapis)

## 6.2. Elementy wykonawcze

Wyświetlacz OLED 0.96” 128×64
- Wyświetla aktualny stan urządzenia
- Pokazuje temperaturę i czas
- Komunikaty w języku polskim
Buzzer
- Krótki beep (20 ms): potwierdzenie akcji

- Dwa beeepy (100 ms): koniec parzenia
- Ciągły beep co 2s: gotowe do picia

## 6.3. Reakcja na zdarzenia zewnętrzne

Zdarzenie | Reakcja systemu
Postawienie kubka | Automatyczne rozpoczęcie parzenia
Zdjęcie kubka | Reset do stanu WAIT_CUP, wyłączenie alarmu
Koniec timera | Dźwięk, przejście do monitorowania temperatury
Osiągnięcie temperatury | Alarm gotowości
Kliknięcie w WAIT_CUP | Wejście do menu konfiguracji

## 6.4. Skrócona instrukcja obsługi

Pierwsze uruchomienie
1. Podłącz zasilacz USB-C 5V/1A
2. Poczekaj na inicjalizację (~3 sekundy)
3. Wyświetlacz pokaże “Brak kubka”
Konfiguracja ustawień
1. Kliknij enkoder - wejście do menu czasu
2. Obracaj enkoder aby ustawić czas parzenia (0-10 min)
3. Kliknij enkoder - wejście do menu temperatury
4. Obracaj enkoder aby ustawić temperaturę docelową (0-100°C)
5. Kliknij enkoder - zapis ustawień i powrót
Użytkowanie
1. Postaw kubek z gorącym napojem na podkładce
2. Timer rozpocznie odliczanie
3. Po zakończeniu odliczania usłyszysz dźwięk
4. System monitoruje temperaturę
5. Gdy napój ostygnie do ustawionej temperatury - alarm gotowości
6. Zdejmij kubek aby wyłączyć alarm

## 6.5. Opis złączy

Złącze J1 (2×5 pin, 5-534237-8)

Łączy płytkę główną z płytką czujników.
J1:

┌─────┐
│ 1 │ 1: 3V3,
├─────┤
│ 2 │ 3: GND,
├─────┤
│ 3 │ 3: SDA,
├─────┤
│ 4 │ 4: SCL
├─────┤
│ 5 │ 5: 3V3,
├─────┤
│ 6 │ 6: GND,
├─────┤
│ 7 │ 7: SDA,
├─────┤
│ 8 │ 8: SCL
├─────┤
│ 9 │ 9: -,
├─────┤
│ 10 │ 10: -
└─────┘

Port USB (NodeMCU)
- Zasilanie: 5V DC
- Programowanie: UART (CP2102)
- Debugowanie: Serial Monitor 115200 baud

## 7. Wnioski i uwagi

## 7.1. Problemy podczas montażu i uruchamiania

Problem 1: Niestabilna komunikacja I2C

Opis: Sporadyczne błędy odczytu z czujników przy wyższych prędkościach I2C. Rozwiązanie: Ustawienie stałej prędkości 100 kHz dla wszystkich urządzeń I2C: Wire.setClock(100000);
Problem 2: Przeskakiwanie wartości enkodera

Opis: Enkoder pomijał kroki lub rejestrował podwójne kliknięcia.
Rozwiązanie: Implementacja pełnego dekodowania z przerwaniami na obu pinach (CHANGE) oraz dzielenie przez 4 (20 impulsów / 4 = 5 kliknięć mechanicznych).

Problem 3: Niedokładna estymacja temperatury

Opis: Temperatura wyświetlana znacząco odbiegała od rzeczywistej temperatury cieczy. Rozwiązanie: Opracowanie adaptacyjnego algorytmu estymacji z tabelą współczynników zależnych od różnicy temperatura-otoczenie oraz snapshot temperatury otoczenia przy postawieniu kubka.

## 7.2. Przeprowadzone testy

Test | Metodyka | Wynik
Detekcja kubka | Umieszczanie różnych kubków (ceramika, szkło, metal) | Poprawna detekcja
Dokładność timera | Pomiar 5-minutowego odliczania stoperem | ±0.5s błędu
Pomiar temperatury | Porównanie z termometrem kuchennym | ±3°C (estymacja)
Zapis EEPROM | 100 cykli zapisu/odczytu | Brak błędów
Stabilność I2C | Praca ciągła 8h | Brak awarii
Enkoder | 500 obrotów w obie strony | Poprawne zliczanie

## 7.3. Wnioski końcowe

Projekt został zrealizowany zgodnie z założeniami. Wszystkie wymagane funkcje działają poprawnie:
Detekcja kubka - czujnik VL6180X wykrywa kubek z wymaganą dokładnością ±0,5 cm
Pomiar temperatury - czujnik MLX90614 z algorytmem estymacji zapewnia przybliżony pomiar temperatury cieczy z dokładnością ±3°C
Timer parzenia - dokładne odliczanie w zakresie 0-10 minut z dokładnością ±1 sekunda Interfejs użytkownika - intuicyjna obsługa enkoderem EC11, czytelny wyświetlacz OLED 128×64
Sygnalizacja dźwiękowa - buzzer pasywny informuje o zakończeniu parzenia i gotowości napoju Zapis ustawień - persist ustawień w pamięci EEPROM między wyłączeniami
Ocena realizacji założeń projektowych:
Założenie | Wymaganie | Osiągnięty wynik | Status
Zasięg detekcji | do 20 cm | 5-200 mm (VL6180X) | Spełnione

Założenie | Wymaganie | Osiągnięty wynik | Status
Dokładność detekcji | ±0,5 cm | ±3 mm | Spełnione
Zakres temperatury | 0-100°C | -40 do +125°C | Spełnione
Dokładność temperatury | ±1°C | ±0,5°C (surowa) | Spełnione
Zakres timera | 0-10 min | 0-600 s | Spełnione
Dokładność timera | ±1 s | ±0,5 s | Spełnione
Zasilanie | 5V DC | 5V/1A USB-C | Spełnione
Wyzwania techniczne:

Największym wyzwaniem okazała się estymacja temperatury cieczy na podstawie pomiaru temperatury dna kubka. Czujnik MLX90614 mierzy temperaturę powierzchni, która różni się od temperatury cieczy. Opracowany algorytm adaptacyjny z tabelą współczynników pozwala na przybliżone określenie temperatury cieczy z dokładnością wystarczającą dla praktycznego zastosowania.
Wnioski dotyczące wyboru komponentów:
1. VL6180X okazał się dobrym wyborem - kompaktowy, dokładny i łatwy w obsłudze
2. MLX90614 spełnia wymagania, ale pomiar bezdotykowy wymaga algorytmu estymacji
3. OLED SSD1306 jest lepszym wyborem niż LCD - mniejszy, czytelniejszy
4. ESP8266 z frameworkiem Arduino zapewnia prostotę programowania i dostęp do bibliotek
5. Konstrukcja dwupłytkowa umożliwia elastyczne rozmieszczenie czujników

## 7.4. Możliwości rozbudowy

1. Integracja WiFi - ESP8266 ma wbudowany moduł WiFi, można dodać:
- Powiadomienia na smartfon
- Integrację z Home Assistant
- Zdalne monitorowanie i sterowanie
- Statystyki użycia (ile herbat dziennie)
2. Podgrzewanie kubka - dodanie elementu grzejnego z regulacją PID
3. Wykrywanie typu napoju - rozpoznawanie na podstawie krzywej stygnięcia
4. Interfejs webowy - panel konfiguracyjny dostępny przez przeglądarkę
5. Obudowa drukowana 3D - estetyczna obudowa z miejscem na kubek

## 8. Literatura

1. Dokumentacja ESP8266 - Espressif Systems, ESP8266 Technical Reference, 2020
2. Datasheet VL6180X - STMicroelectronics, VL6180X Proximity and ambient light sensing module
3. Datasheet MLX90614 - Melexis, MLX90614 Single and Dual Zone Infra Red Thermometer
4. Datasheet SSD1306 - Solomon Systech, SSD1306 Advance Information
5. Biblioteka ss_oled - https://github.com/bitbank2/ss_oled
6. Biblioteka Adafruit_MLX90614 - https://github.com/adafruit/Adafruit-MLX90614-Library
7. Biblioteka Adafruit_VL6180X - https://github.com/adafruit/Adafruit_VL6180X
8. PlatformIO Documentation - https://docs.platformio.org/
9. Materiały pomocnicze do projektu SMiW - Jarosław Paduch, Katedra Grafiki, Wizji Komputerowej i Systemów Cyfrowych, Politechnika Śląska, 2023

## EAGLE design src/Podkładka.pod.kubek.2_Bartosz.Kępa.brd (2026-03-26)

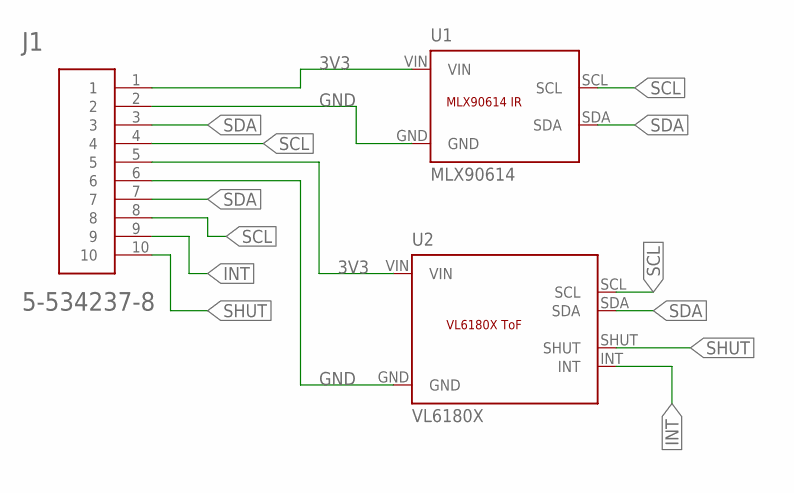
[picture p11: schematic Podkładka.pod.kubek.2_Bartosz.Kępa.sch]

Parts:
J1: 5-534237-8
U1: MLX90614; MLX90614_MODULE
U2: VL6180X; VL6180X_MODULE

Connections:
3V3: J1.1, J1.5, U1.VIN, U2.VIN
GND: J1.2, J1.6, U1.GND, U2.GND
INT: J1.9, U2.INT
SCL: J1.4, J1.8, U1.SCL, U2.SCL
SDA: J1.3, J1.7, U1.SDA, U2.SDA
SHUT: J1.10, U2.SHUT

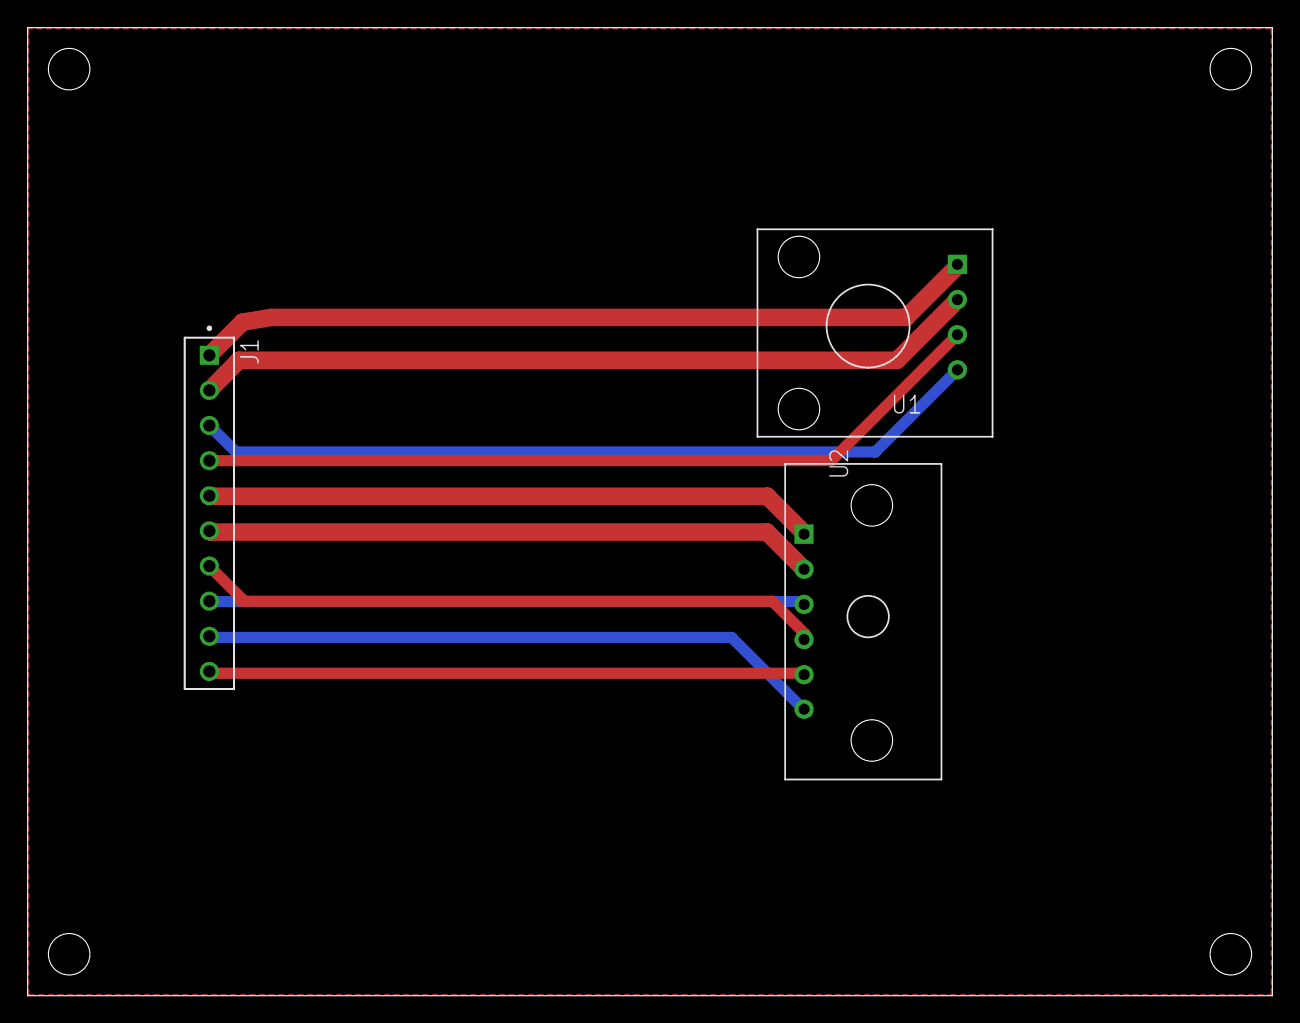
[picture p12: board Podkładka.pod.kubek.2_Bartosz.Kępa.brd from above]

Board: 2 copper layers, 90.0 x 70.0 mm, 3 parts (0 on the bottom side), 6 nets.

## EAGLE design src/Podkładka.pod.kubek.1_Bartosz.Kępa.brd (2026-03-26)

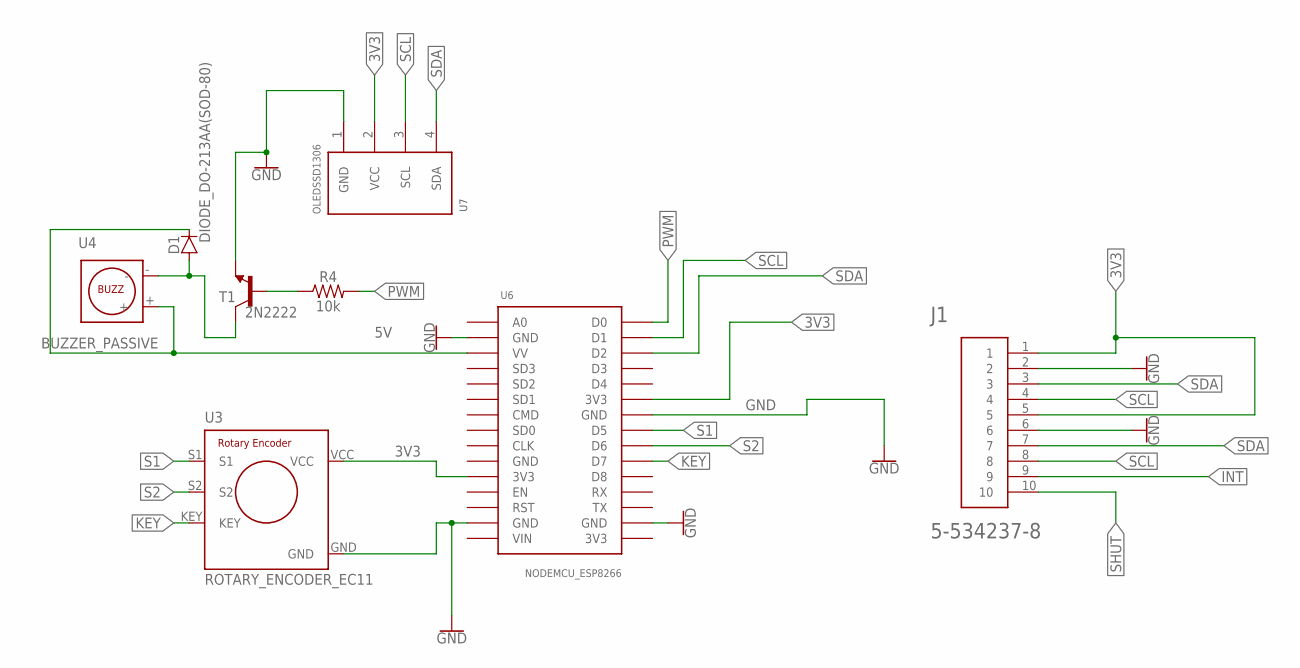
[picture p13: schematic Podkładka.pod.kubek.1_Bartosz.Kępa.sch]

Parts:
D1: DIODE_DO-213AA(SOD-80); DIOMELF3516
J1: 5-534237-8
OLEDSSD1306: I2C_OLED; I2C_OLED_PACKAGE
R4: 10k; AXIAL-0.3
T1: 2N2222; TO92-EBC-OVAL
U3: ROTARY_ENCODER_EC11; EC11_ROTARY_ENCODER
U4: BUZZER_PASSIVE; BUZZER_PASSIVE_12MM
U6: NODEMCU_ESP8266

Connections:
3V3: J1.1, J1.5, OLEDSSD1306.2 (VCC), U3.VCC, U6.3V3@1 (3V3), U6.3V3@2 (3V3), U6.3V3@3 (3V3)
5V: D1.1 (C), U4.+, U6.VV
GND: J1.2, J1.6, OLEDSSD1306.1 (GND), T1.E, U3.GND, U6.GND@1 (GND), U6.GND@2 (GND), U6.GND@3 (GND), U6.GND@4 (GND), U6.GND@5 (GND)
INT: J1.9
KEY: U3.KEY, U6.D7
unnamed: R4.P$1 (1), T1.B
unnamed: D1.2 (A), T1.C, U4.-
PWM: R4.P$2 (2), U6.D0
S1: U3.S1, U6.D5
S2: U3.S2, U6.D6
SCL: J1.4, J1.8, OLEDSSD1306.3 (SCL), U6.D1
SDA: J1.3, J1.7, OLEDSSD1306.4 (SDA), U6.D2
SHUT: J1.10
VIN: U6.VIN

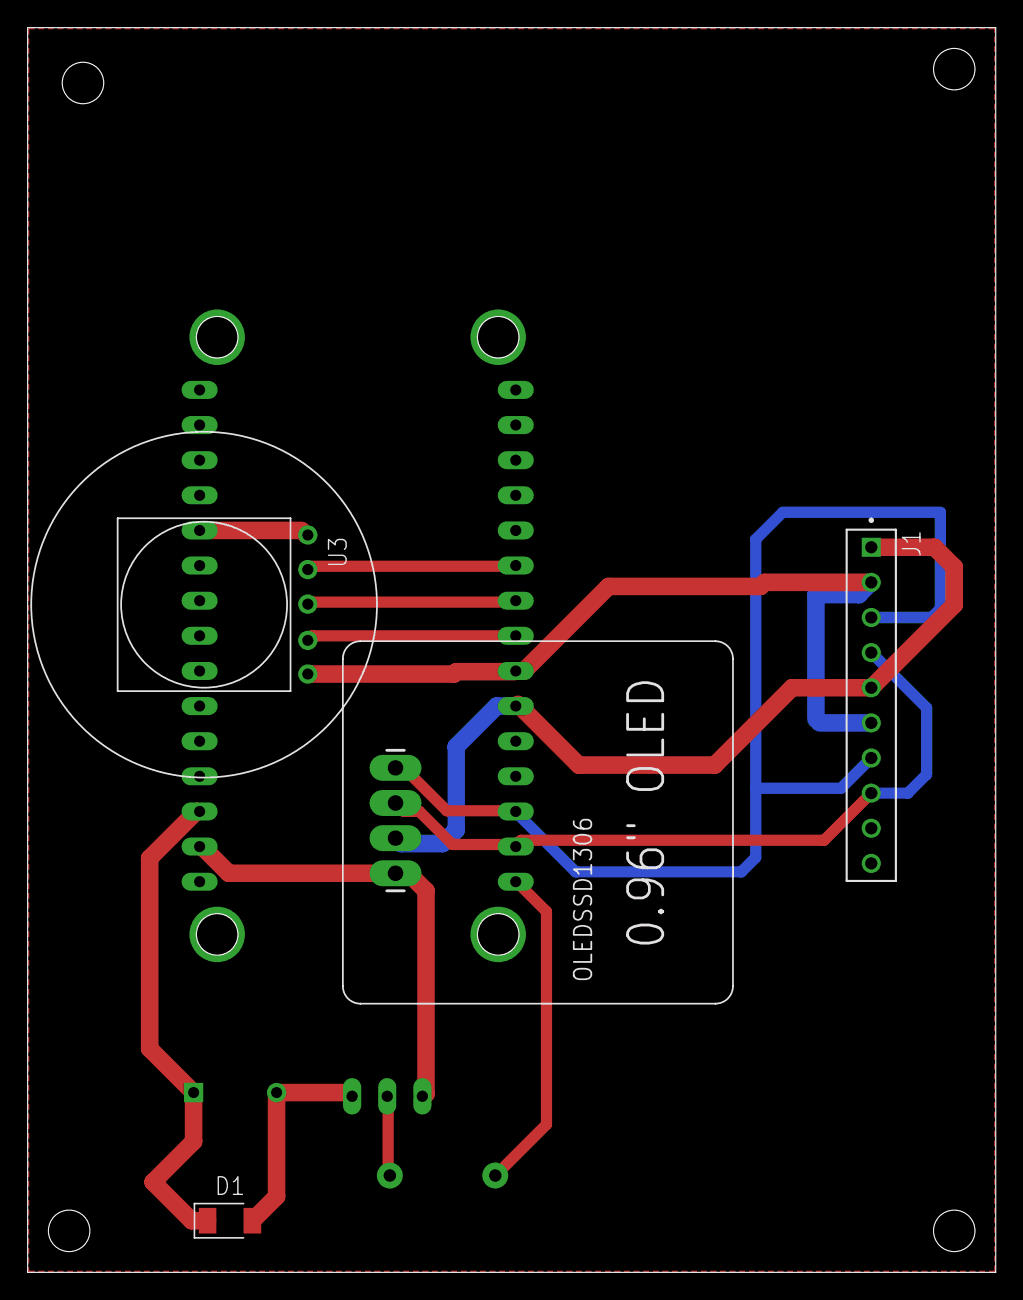
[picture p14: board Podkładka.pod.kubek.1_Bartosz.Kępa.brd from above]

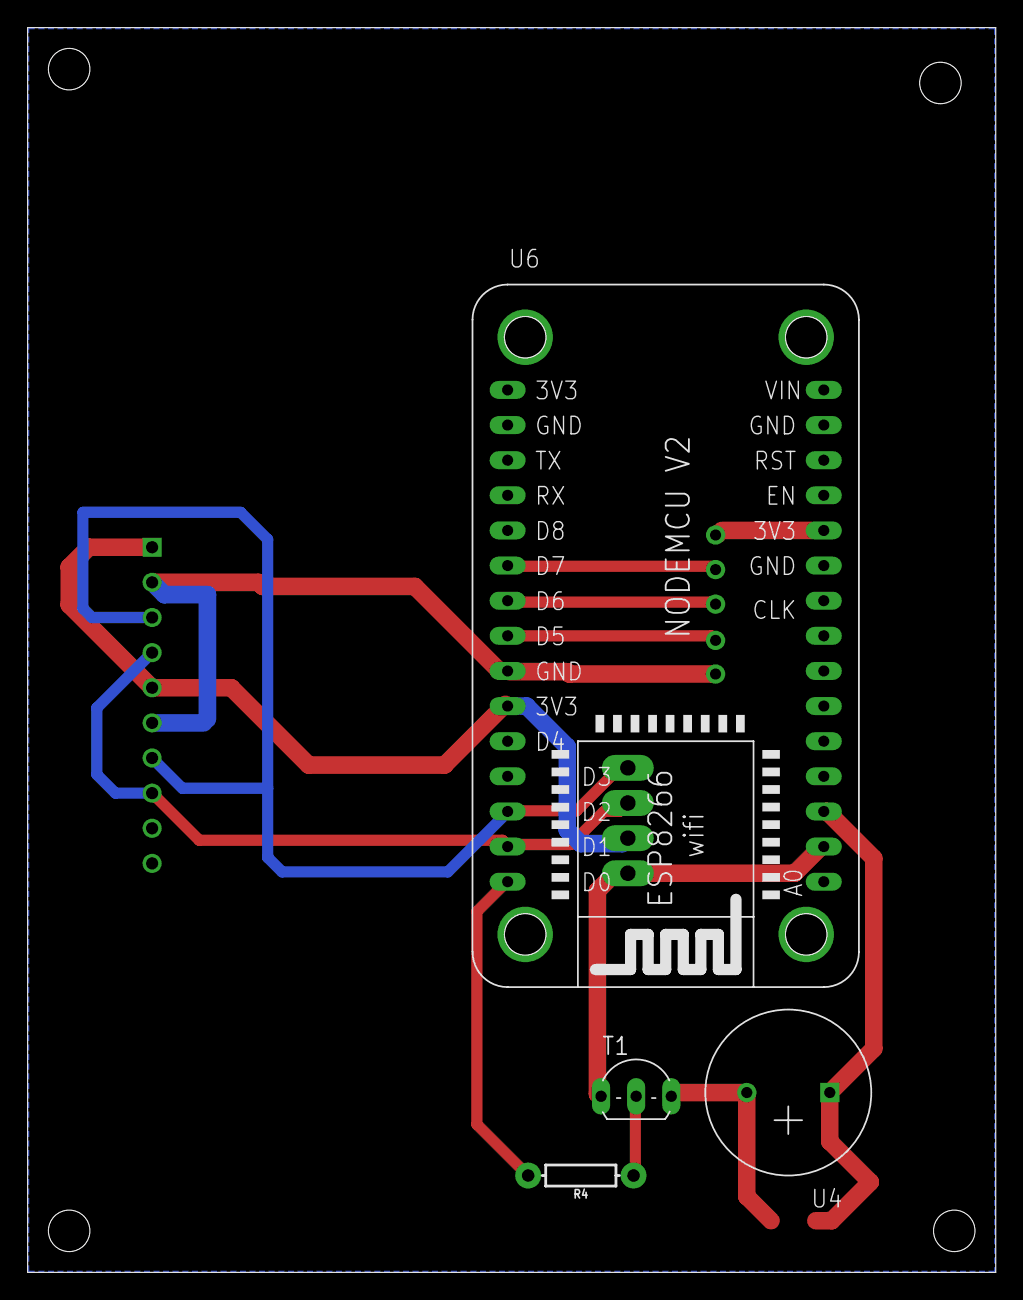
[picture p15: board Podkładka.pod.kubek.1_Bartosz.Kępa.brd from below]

Board: 2 copper layers, 70.0 x 90.0 mm, 8 parts (4 on the bottom side), 11 nets.

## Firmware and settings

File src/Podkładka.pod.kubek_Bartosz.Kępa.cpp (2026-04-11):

#include <Arduino.h>
#include <Wire.h>
#include <ss_oled.h>
#include <Adafruit_MLX90614.h>
#include <Adafruit_VL6180X.h>
#include <EEPROM.h>

#include <ESP8266WiFi.h>
#include <ESP8266HTTPClient.h>

const char* ssid = "tplink1";
const char* password = "888811288";
const char* ntfy_url = "http://ntfy.sh/Coaster";

void triggerReady();
float estimateLiquidTemp(float rawBottomTemp, float ambientTemp);
void handleEncoder();
void encoderClick();
void adjustTime(int d);
void adjustTemp(int d);
void checkDisplayUpdate();
void drawScreenContent();
void formatTime(long sec, char* buf);
void beep(int f, int d);
void loadSettings();
void saveSettings();
float measureDistance();
void startBrewing();
long remaining();
void finishBrewing();
void wakeDisplay();
void sendPhoneNotification();

#define SAFETY_TEMP_THRESHOLD 45.0

SSOLED ssoled;
#define OLED_ADDR 0x3C
#define SDA_PIN D2
#define SCL_PIN D1

// ================== PINY ==================
#define ENC_S1 D5
#define ENC_S2 D6
#define ENC_KEY D7
#define BUZZER_PIN D0

#define MAX_DISTANCE 50
#define MIN_TIME 0
#define MAX_TIME 600
#define DEFAULT_TIME 180
#define MIN_TEMP 0
#define MAX_TEMP 100
#define DEFAULT_TEMP 55

#define EEPROM_SIZE 64
#define ADDR_TIME 0
#define ADDR_TEMP 10

Adafruit_MLX90614 mlx = Adafruit_MLX90614();
Adafruit_VL6180X vl = Adafruit_VL6180X();

// ================== ZMIENNE ==================
unsigned long brewDuration;
unsigned long brewStartTime;
unsigned long timeSet = DEFAULT_TIME;
float tempThreshold = DEFAULT_TEMP;

enum State {
  WAIT_CUP,
  MENU_TIME,
  MENU_TEMP,
  BREWING,
  DONE,
  READY_TO_DRINK
};
State state = WAIT_CUP;
State lastDrawnState = (State)-1;

unsigned long lastDistanceCheck = 0;
unsigned long lastTempUpdate = 0;
bool cupDetected = false;
bool lastCupDetected = false;
float currentTemp = 0.0;
float rawBottomTemp = 0.0;
bool tempWarningShown = false;
float peakTemp = 0.0;

// --- AUTO-KALIBRACJA ---
float fixedAmbient = 22.0;          // Snapshot temp otoczenia
float peakBottomTemp = 0.0;         // Peak temp dna 
unsigned long calibrationTime = 0;  // Kiedy wykryto peak

// Alarm
unsigned long lastReadyBeepTime = 0;

// Śledzenie temperatury
float lastStableTemp = 0.0;
unsigned long stableTempSince = 0;
const unsigned long STABLE_TIMEOUT = 60000;

// ================== WYGASZANIE EKRANU ==================
unsigned long lastActivityTime = 0;
bool isDisplayAwake = true;
const unsigned long SLEEP_TIMEOUT = 300000; 

// ================== ZMIENNE ENKODERA Z PRZERWANIAMI I QUADRATURE ==================
volatile int encoderPosition = 0;
volatile int lastEncoded = 0;

unsigned long lastButtonTime = 0;

bool needDisplayUpdate = true;
unsigned long lastDisplayDrawTime = 0;
const int DISPLAY_REFRESH_INTERVAL = 50;

char buffer[20];

void IRAM_ATTR handleEncoderInterrupt() {
  int MSB = digitalRead(ENC_S1);
  int LSB = digitalRead(ENC_S2);

  int encoded = (MSB << 1) | LSB;
  int sum = (lastEncoded << 2) | encoded;
 
  if(sum == 0b1101 || sum == 0b0100 || sum == 0b0010 || sum == 0b1011) {
    encoderPosition++;
  }
  if(sum == 0b1110 || sum == 0b0111 || sum == 0b0001 || sum == 0b1000) {
    encoderPosition--;
  }

  lastEncoded = encoded; // Zapisz aktualny stan
}

void wakeDisplay() {
  lastActivityTime = millis();
  if (!isDisplayAwake) {
    isDisplayAwake = true;
    needDisplayUpdate = true;
    lastDrawnState = (State)-1;
  }
}

void sendPhoneNotification() {
  if (WiFi.status() == WL_CONNECTED) {
    WiFiClient client;
    HTTPClient http;
    http.begin(client, ntfy_url);
    http.addHeader("Title", "Smart Coaster"); 
    http.addHeader("Priority", "5"); 
    http.addHeader("Tags", "rotating_light,alarm_clock");
    http.POST("Twój napój osiągnął idealną temperaturę i jest gotowy do picia!");
    http.end();
  }
}

void triggerReady() {
  state = READY_TO_DRINK;
  tempWarningShown = true;
  stableTempSince = 0;
  lastStableTemp = 0;
  lastReadyBeepTime = 0;
  wakeDisplay();
  needDisplayUpdate = true;
  sendPhoneNotification();
}

float estimateLiquidTemp(float rawBottomTemp, float ambientTemp) {
  if (isnan(rawBottomTemp) || rawBottomTemp < ambientTemp) {
    return ambientTemp;
  }

  float diff = rawBottomTemp - ambientTemp;
  if (diff < 0) diff = 0;

  float baseFactor = 0.08;
  float adaptiveCoeff;

  // POPRAWIONE PROGI
  if (diff > 51) {
    adaptiveCoeff = baseFactor * 1.0;      // >95°C 
  } 
  else if (diff > 50) {
    adaptiveCoeff = baseFactor * 0.95;      // 90-95°C
  } 
  else if (diff > 45) {
    adaptiveCoeff = baseFactor * 0.85;      // 80-90°C 
  }
  else if (diff > 40) {
    adaptiveCoeff = baseFactor * 0.80;     // 70-80°C
  } 
  else if (diff > 30) {
    adaptiveCoeff = baseFactor * 0.75;     // 60-70°C 
  } 
  else if (diff > 20) {
    adaptiveCoeff = baseFactor * 0.65;     // 50-60°C
  } 
  else {
    adaptiveCoeff = baseFactor * 0.50;     // <50°C 
  }

  float liquidTemp = rawBottomTemp + (diff * adaptiveCoeff);
  return liquidTemp;
}

void setup() {
  Serial.begin(9600);
  Serial.println("\n=== START ===");

  WiFi.begin(ssid, password);
  int retries = 0;
  while (WiFi.status() != WL_CONNECTED && retries < 20) {
    delay(500);
    retries++;
  }

  EEPROM.begin(EEPROM_SIZE);
  loadSettings();

  pinMode(ENC_S1, INPUT);
  pinMode(ENC_S2, INPUT);
  pinMode(ENC_KEY, INPUT);
  pinMode(BUZZER_PIN, OUTPUT);
  
  // Podłącz przerwania do OBUDU pinów enkodera dla pełnej detekcji
  attachInterrupt(digitalPinToInterrupt(ENC_S1), handleEncoderInterrupt, CHANGE);
  attachInterrupt(digitalPinToInterrupt(ENC_S2), handleEncoderInterrupt, CHANGE);
  
  // Inicjalizacja stanu enkodera
  int MSB = digitalRead(ENC_S1);
  int LSB = digitalRead(ENC_S2);
  lastEncoded = (MSB << 1) | LSB;

  Wire.begin(SDA_PIN, SCL_PIN);
  Wire.setClock(100000);

  delay(50);

  int rc = oledInit(&ssoled, OLED_128x64, OLED_ADDR, 1, 0, 1, SDA_PIN, SCL_PIN, -1, 100000L);
  if (rc != OLED_NOT_FOUND) {
    Serial.println("OLED OK");
  }

  oledFill(&ssoled, 0, 1);
  oledWriteString(&ssoled, 0, 0, 2, (char*)"Coaster", FONT_NORMAL, 0, 1);

  delay(200);

  bool mlxOK = mlx.begin();
  Serial.println(mlxOK ? "MLX OK" : "MLX ERROR");

  bool vlOK = vl.begin();
  Serial.println(vlOK ? "VL OK" : "VL ERROR");

  bool wifiOK = (WiFi.status() == WL_CONNECTED);

  oledFill(&ssoled, 0, 1);
  oledWriteString(&ssoled, 0, 0, 1, (char*)"System:", FONT_NORMAL, 0, 1);
  oledWriteString(&ssoled, 0, 0, 3, mlxOK ? (char*)"MLX: OK" : (char*)"MLX: ERR", FONT_NORMAL, 0, 1);
  oledWriteString(&ssoled, 0, 0, 5, vlOK ? (char*)"VL: OK" : (char*)"VL: ERR", FONT_NORMAL, 0, 1);
  oledWriteString(&ssoled, 0, 0, 7, wifiOK ? (char*)"WIFI: OK" : (char*)"WIFI: ERR", FONT_NORMAL, 0, 1);

  delay(1500);

  oledFill(&ssoled, 0, 1);

  needDisplayUpdate = true;
  fixedAmbient = mlx.readAmbientTempC();
  lastActivityTime = millis(); // Inicjalizacja timera ekranu
}

// ================== LOOP ==================
void loop() {
  unsigned long now = millis();
  

  handleEncoder();

  // --- LOGIKA USYPIANIA EKRANU ---
  if (isDisplayAwake && (now - lastActivityTime > SLEEP_TIMEOUT)) {
    isDisplayAwake = false;
    oledFill(&ssoled, 0, 1);
  }

  // 1. Sprawdzanie odległości z ochroną termiczną
  if (state != MENU_TIME && state != MENU_TEMP && now - lastDistanceCheck >= 400) {
    lastDistanceCheck = now;

    bool nowCup = false;

    if (currentTemp > SAFETY_TEMP_THRESHOLD) {
      nowCup = true;
    } else {
      float d = measureDistance();
      nowCup = (d > 0 && d <= MAX_DISTANCE);
    }

    if (nowCup != cupDetected) {
      wakeDisplay(); // Wybudź ekran przy zmianie stanu kubka!

      cupDetected = nowCup;

      if (cupDetected && state == WAIT_CUP) {
        // SNAPSHOT temp otoczenia przy postawieniu kubka

        // Jeśli podstawka gorąca, użyj standardowej temp
        if (fixedAmbient > 23.0 || isnan(fixedAmbient)) {
          fixedAmbient = 23.0;
        }

        Serial.print("Kubek postawiony, ambient snapshot: ");
        Serial.print(fixedAmbient);
        Serial.println("C");

        brewDuration = timeSet;
        delay(100);
        startBrewing();
      } else if (!nowCup) {
        // Kubek zdjęty - reset wszystkiego
        peakTemp = 0.0;
        peakBottomTemp = 0.0;
        needDisplayUpdate = true;
        noTone(BUZZER_PIN);

        Serial.println("Kubek zdjety - reset kalibracji");
      }
    }
  }

  // 2. Alarm gotowości
  if (state == READY_TO_DRINK && cupDetected) {
    unsigned long diff = now - lastReadyBeepTime;
    if (diff >= 2000) {
      lastReadyBeepTime = now;
      beep(2000, 500);
    }
  } else if (!cupDetected && state == READY_TO_DRINK) {
    noTone(BUZZER_PIN);
  }

  // 3. Odczyt temperatury i logika
  if (cupDetected && (state == BREWING || state == DONE || state == READY_TO_DRINK)
      && now - lastTempUpdate >= 1000) {
    lastTempUpdate = now;

    rawBottomTemp = mlx.readObjectTempC();

    if (isnan(rawBottomTemp) || rawBottomTemp < 0) rawBottomTemp = 0;

    // Używamy snapshot ambient zamiast bieżącego
    currentTemp = estimateLiquidTemp(rawBottomTemp, fixedAmbient);

    if (currentTemp > peakTemp) peakTemp = currentTemp;

    // Debug info
    if (now % 5000 < 1100) {  // Co ~5 sekund
      Serial.print("Raw: ");
      Serial.print(rawBottomTemp);
      Serial.print("C, Est: ");
      Serial.print(currentTemp);
      Serial.print("C, Peak: ");
      Serial.print(peakTemp);
      Serial.print("\n");
    }

    // Logika wykrywania gotowości
    if (state == DONE && !tempWarningShown) {
      if ((int)currentTemp <= (int)tempThreshold) {
        if (peakTemp > 0 && currentTemp < peakTemp - 2.0) {
          triggerReady();
        } else if (lastStableTemp != 0 && millis() - stableTempSince > 10000) {
          triggerReady();
        }
      }

      if (lastStableTemp == 0) {
        lastStableTemp = currentTemp;
        stableTempSince = millis();
      }

      float tempDiff = currentTemp - lastStableTemp;
      if (tempDiff >= 0.3 || tempDiff <= -0.3) {
        lastStableTemp = currentTemp;
        stableTempSince = millis();
      }
    }
    needDisplayUpdate = true;
  }

  // 4. Reset stanu po zdjęciu kubka
  if ((state == BREWING || state == DONE || state == READY_TO_DRINK) && !cupDetected) {
    state = WAIT_CUP;
    peakTemp = 0.0;
    peakBottomTemp = 0.0;
    tempWarningShown = false;
    lastStableTemp = 0;
    stableTempSince = 0;
    noTone(BUZZER_PIN);
    needDisplayUpdate = true;
  }

  // 5. Timer parzenia
  if (state == BREWING) {
    if (remaining() <= 0) finishBrewing();
    needDisplayUpdate = true;
  }

  checkDisplayUpdate();
}

void handleEncoder() {
  static int lastPosition = 0;
  
  
  int currentPosition = encoderPosition / 4;
  

  if (currentPosition != lastPosition) {
    int delta = currentPosition - lastPosition;
    lastPosition = currentPosition;
    
    wakeDisplay(); // Wybudź ekran po obróceniu enkodera!
    

    int timeStep = 10; 
    int tempStep = 1;    
    

    if (state == MENU_TIME) {
      adjustTime(delta * timeStep);
    } else if (state == MENU_TEMP) {
      adjustTemp(delta * tempStep);
    }
  }
  
  // Obsługa przycisku
  unsigned long now = millis();
  if (digitalRead(ENC_KEY) == LOW) {
    if (now - lastButtonTime > 250) {
      lastButtonTime = now;
      
      wakeDisplay();
      encoderClick();
      while (digitalRead(ENC_KEY) == LOW) delay(10);
    }
  }
}

void encoderClick() {
  State oldState = state;
  if (state == WAIT_CUP) state = MENU_TIME;
  else if (state == MENU_TIME) state = MENU_TEMP;
  else if (state == MENU_TEMP) {
    state = WAIT_CUP;
    saveSettings();
    beep(2500, 20);
  }
  if (oldState != state) {
    beep(2000, 20);
    needDisplayUpdate = true;
  }
}

void adjustTime(int d) {
  timeSet = constrain((long)timeSet + d, MIN_TIME, MAX_TIME);
  needDisplayUpdate = true;
}

void adjustTemp(int d) {
  tempThreshold = constrain(tempThreshold + d, MIN_TEMP, MAX_TEMP);
  needDisplayUpdate = true;
}

void checkDisplayUpdate() {
  if (!isDisplayAwake) return; 

  if (needDisplayUpdate && (millis() - lastDisplayDrawTime > DISPLAY_REFRESH_INTERVAL)) {
    lastDisplayDrawTime = millis();
    needDisplayUpdate = false;

    if (state != lastDrawnState || cupDetected != lastCupDetected) {
      oledFill(&ssoled, 0, 1);
      lastDrawnState = state;
      lastCupDetected = cupDetected;
    }

    drawScreenContent();
  }
}


void drawScreenContent() {
  int tempInt = (int)currentTemp;

  if (state == WAIT_CUP) {
    if (!cupDetected) {
      oledWriteString(&ssoled, 0, 20, 1, (char*)"Brak    ", FONT_STRETCHED, 0, 1);
      oledWriteString(&ssoled, 0, 12, 4, (char*)"kubka   ", FONT_STRETCHED, 0, 1);
      oledWriteString(&ssoled, 0, 8, 7, (char*)"Klik = Menu     ", FONT_NORMAL, 0, 1);
    } else {
      oledWriteString(&ssoled, 0, 12, 2, (char*)"Kubek   ", FONT_STRETCHED, 0, 1);
      oledWriteString(&ssoled, 0, 0, 5, (char*)"wykryty ", FONT_STRETCHED, 0, 1);
    }
  } else if (state == MENU_TIME) {
    oledWriteString(&ssoled, 0, 0, 0, (char*)"Czas parzenia:  ", FONT_NORMAL, 0, 1);
    formatTime(timeSet, buffer);
    strcat(buffer, "  ");
    oledWriteString(&ssoled, 0, 14, 3, buffer, FONT_STRETCHED, 0, 1);
  } else if (state == MENU_TEMP) {
    oledWriteString(&ssoled, 0, 0, 0, (char*)"Ustaw Temp:     ", FONT_NORMAL, 0, 1);
    sprintf(buffer, "%d C  ", (int)tempThreshold);
    oledWriteString(&ssoled, 0, 20, 3, buffer, FONT_STRETCHED, 0, 1);
    oledWriteString(&ssoled, 0, 0, 7, (char*)"(Temp cieczy)", FONT_NORMAL, 0, 1);
  } else if (state == BREWING) {
    oledWriteString(&ssoled, 0, 4, 0, (char*)"Parzenie", FONT_STRETCHED, 0, 1);
    formatTime(remaining(), buffer);
    strcat(buffer, " ");
    oledWriteString(&ssoled, 0, 14, 3, buffer, FONT_STRETCHED, 0, 1);
    sprintf(buffer, "Liq: %d C       ", tempInt);
    oledWriteString(&ssoled, 0, 8, 7, buffer, FONT_NORMAL, 0, 1);
  } else if (state == DONE) {
    if(currentTemp < tempThreshold){
    oledWriteString(&ssoled, 0, 4, 0, (char*)"Grzanie ", FONT_STRETCHED, 0, 1);
    }
    else{
     oledWriteString(&ssoled, 0, 4, 0, (char*)"Stygnie ", FONT_STRETCHED, 0, 1);
    }
    sprintf(buffer, "Cel: %d C       ", (int)tempThreshold);
    oledWriteString(&ssoled, 0, 16, 4, buffer, FONT_NORMAL, 0, 1);
    sprintf(buffer, "Akt: %d C       ", tempInt);
    oledWriteString(&ssoled, 0, 16, 6, buffer, FONT_NORMAL, 0, 1);
  } else if (state == READY_TO_DRINK) {
    oledWriteString(&ssoled, 0, 4, 0, (char*)"GOTOWE! ", FONT_STRETCHED, 0, 1);
    sprintf(buffer, "%d C  ", tempInt);
    oledWriteString(&ssoled, 0, 28, 4, buffer, FONT_STRETCHED, 0, 1);
  }
}

void formatTime(long sec, char* buf) {
  int m = sec / 60;
  int s = sec % 60;
  sprintf(buf, "%02d:%02d", m, s);
}

void beep(int f, int d) {
  tone(BUZZER_PIN, f, d);
}

void loadSettings() {
  long readTime;
  float readTemp;
  EEPROM.get(ADDR_TIME, readTime);
  EEPROM.get(ADDR_TEMP, readTemp);
  timeSet = (readTime >= MIN_TIME && readTime <= MAX_TIME) ? readTime : DEFAULT_TIME;
  tempThreshold = (!isnan(readTemp) && readTemp >= MIN_TEMP && readTemp <= MAX_TEMP) ? readTemp : DEFAULT_TEMP;
}

void saveSettings() {
  EEPROM.put(ADDR_TIME, timeSet);
  EEPROM.put(ADDR_TEMP, tempThreshold);
  EEPROM.commit();
}

float measureDistance() {
  uint8_t range = vl.readRange();
  return (vl.readRangeStatus() == VL6180X_ERROR_NONE) ? range : -1;
}

void startBrewing() {
  state = BREWING;
  brewStartTime = millis();
  peakTemp = 0.0;
  peakBottomTemp = 0.0;
  tempWarningShown = false;
  lastStableTemp = 0;
  stableTempSince = 0;
  beep(1000, 200);
  wakeDisplay(); // Wybudź ekran przy starcie parzenia
  needDisplayUpdate = true;
}

long remaining() {
  unsigned long passed = (millis() - brewStartTime) / 1000;
  return (brewDuration > passed) ? brewDuration - passed : 0;
}


void finishBrewing() {
  state = DONE;
  lastStableTemp = 0;
  stableTempSince = 0;
  for (int i = 0; i < 2; i++) {
    beep(1500, 100);
    delay(100);
  }
  wakeDisplay(); // Wybudź ekran po zakończeniu parzenia
  needDisplayUpdate = true;
}

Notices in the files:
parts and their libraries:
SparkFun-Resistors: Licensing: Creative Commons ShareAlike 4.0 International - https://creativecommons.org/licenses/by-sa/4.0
